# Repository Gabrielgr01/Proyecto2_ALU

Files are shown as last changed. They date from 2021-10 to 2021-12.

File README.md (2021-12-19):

# Diseño e implementación de una ALU
Diseño e implementación de una Unidad Aritmético Lógica (ALU).

Entradas:
- Primer número de 6 bits en complemento a 2
- Segundo número de 6 bits en complemento a 2
- Selector de 3 bits, para seleccionar la operación

Operaciones:
- XOR
- AND
- OR
- Desplazamiento hacia la derecha
- Suma con signo
- Multiplicación con signo
- Resta con signo
- Quintuplicador con signo

Salidas:
- Resultado númerico en complemento a 2
- Bandera de cero
- Bandera de paridad par
- Bandera de desbordamiento (Overflow)

Colaboradores:
- Adrián Dittel Retana
- Gabriel O. González Rodríguez
- Emmanuel Naranjo Blanco
- José Fabio Navarro Naranjo
- David Rodríguez Camacho

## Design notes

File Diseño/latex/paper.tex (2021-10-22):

\documentclass[journal,trans]{IEEEtran}

\usepackage[utf8]{inputenc}
\usepackage{graphicx}
\usepackage[spanish, es-tabla, activeacute]{babel}
\usepackage{verbatim}

\begin{document}

% Do not put math or special symbols in the title.
\newcommand{\titlepaper}{Diseño e Implementación de una ALU}

\title{\titlepaper}

\renewcommand\IEEEkeywordsname{Palabras clave}

\author{\IEEEauthorblockN{Adrián Dittel-Retana, Gabriel O. González-Rodríguez, Emmanuel Naranjo-Blanco, Jose Fabio Navarro-Naranjo, David Rodríguez-Camacho}

\IEEEauthorblockA{adriandittel19@estudiantec.cr}
\IEEEauthorblockA{gabrielgr01@estudiantec.cr}
\IEEEauthorblockA{naranjo760emm@estudiantec.cr}
\IEEEauthorblockA{josefabio1127@estudiantec.cr}
\IEEEauthorblockA{davo4006@estudiantec.cr}
\IEEEauthorblockA{\\Área Académica de Ingeniería Mecatrónica}
\IEEEauthorblockA{\\Instituto Tecnológico de Costa Rica}
}

% The paper headers
\markboth{Dittel, González, Naranjo, Navarro, Rodríguez, \titlepaper}%
{Shell \MakeLowercase{\textit{et al.}}: Bare Demo of IEEEtran.cls for Journals}

\IEEEtitleabstractindextext{%
\begin{abstract}
La Unidad Aritmética Lógica (ALU) consiste en una parte esencial de la unidad central de procesamiento, encargada de realizar operaciones lógicas y aritméticas para cumplir instrucciones dentro de un sistema computacional. En el presente proyecto de laboratorio se presentará una propuesta para el diseño de una ALU que lleva a cabo siete operaciones (lógicas y matemáticas), además de los resultados obtenidos tras su ejecución. La solución a la propuesta se basó fundamentalmente en el uso de lógica combinacional, y a nivel de diseño se utilizó el método de diseño modular, en donde se divide el sistema en subsistemas más pequeños, llamados módulos, a los cuales se les encuentra una solución individual, y reutilizable.  Posteriormente se integran las soluciones para cada módulo y se le agregan las distintas banderas como parte de las restricciones del proyecto. Una vez finalizado el experimento, se llega a la conclusión principal del proyecto: Se verificó mediante el lenguaje de descripción de hardware (HDL), y su implementación en la placa de desarrollo BASYS 3, el correcto funcionamiento de la ALU propuesta mediante la estructura de diseño planteada. Además, de la simulación se obtuvo, para la FPGA utilizada, un bajo consumo de potencia (5.576W) y una utilización del LUT (Look Up Table) de 0.33\%, lo que significa que también hubo un bajo consumo de memoria.
\end{abstract}

\begin{IEEEkeywords}
Diseño modular, ALU, Lógica Combinacional, Verilog.
\end{IEEEkeywords}}

\maketitle
\IEEEdisplaynontitleabstractindextext
\IEEEpeerreviewmaketitle

\section{INTRODUCCIÓN}

Parte fundamental de la electrónica digital consiste en la implementación de los conocimientos en la integración de sistemas completamente funcionales y aplicables para solucionar problemas de la vida real. En el presente proyecto de laboratorio se pretende aplicar la teoría, específicamente aquella relacionada con lógica combinacional, para así emplearla de forma práctica en una Unidad Aritmética Lógica (ALU, por sus siglas en inglés). 

De acuerdo con Tocci, una ALU consiste en un circuito que permite realizar operaciones lógicas y aritméticas \cite{Tocci}. Las cuales se encuentran como parte fundamental de los sistemas tecnológicos actuales como computadoras, celulares y tablets. A su vez, existen presentaciones en circuitos integrados como los chips 74LS382 o 74HC382 cuyo bloque se representa en la Figura \ref{fig:ALU}. 

En este tipo de chips se basa el objetivo específico del proyecto, el cual consiste en implementar un sistema lógico en un ambiente de verificación de hardware. Donde como parte de los objetivos generales se tiene comprender el proceso de diseño y verificación de los sistemas digitales, y aplicar el diseño en una placa de desarrollo. Para este caso se utiliza una matriz de puertas lógicas programable en campo, comúnmente llamada FPGA (Field-Programmable Gate Array).

\begin{figure}[!h]
	\centering
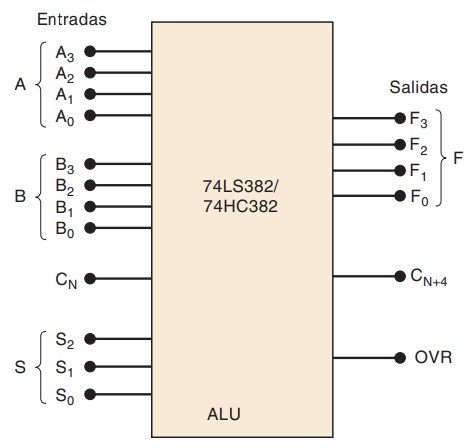
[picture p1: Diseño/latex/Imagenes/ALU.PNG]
	
	\caption{Símbolo de bloque para el chip ALU 74LS382/HC382 \cite{Tocci}.}
	\label{fig:ALU}
\end{figure}

La idea fundamental de este proyecto consiste en diseñar una ALU que realice todas las operaciones descritas en la Tabla \ref{tab:operaciones}. Para esto se tienen dos entradas de datos A y B, y una salida Y, todas con un tamaño constante de palabra de 6 bits y operando bajo el sistema de complemento a dos. Además, las operaciones se escogen mediante un selector SEL de 3 bits y se requiere de tres banderas: cero, paridad par y desbordamiento. 

\begin{table}[!h]
  \begin{center}
    \caption{Descripción de las operaciones de la ALU por diseñar.}
    \label{tab:operaciones}
    \begin{tabular}{c | c | c }
      \hline
      SEL [2:0] & Tipo de Operación & Y \\
      \hline
       000 & XOR & Y = A $\string^$ B \\
       \hline
       001 & AND & Y = A $\&$ B \\
       \hline
       010 & OR & Y = A $\mid$ B \\
       \hline
       011 & Desplazamiento lógico a la derecha & Y=A $\gg$ 1 \\
       \hline
       100 & Suma con signo & Y = A + B \\
       \hline
       101 & Multiplicación con signo & Y = A * B \\
       \hline
       110 & Resta con signo & Y = A - B \\
       \hline
       111 & Quintuplicado de un número & Y = 5 * A \\
      \hline
    \end{tabular}
  \end{center}
\end{table}

Para simular e implementar el diseño propuesto se utiliza la placa BASYS 3 Artix-7 (xc7a35tcpg236-2L), la cual se programa en Verilog, un lenguaje de descripción de hardware (HDL, por sus siglas en inglés) al cual se le realiza una previa simulación para comprobar su correcto funcionamiento.

A modo conceptual, un HDL se trata de un lenguaje de programación para modelar un bloque de hardware, el cual permite simular la operación del circuito antes de fabricarlo \cite{Paulino}. En este caso, se trabajó con el HDL Verilog debido a su popularidad y simplicidad, y por ser estándar en la industria de las FPGA. Para esto, cada componente se describe con módulos y la verificación de este se establece bajo la estructura de un TestBench.

En las siguientes secciones se detallará el proceso de diseño junto con los diagramas modulares realizados y su descripción. Posteriormente se analizarán los resultados obtenidos tanto a nivel físico como simulado mediante el software Vivado. 

\section{DISEÑO DE LA ALU}

Para el desarrollo de la ALU anteriormente descrita, se utilizó un diseño modular, desarrollado y ejemplificado a través de diagramas de primer, segundo y tercer nivel (ver anexos).

Las restricciones previamente definidas para el proyecto son las siguiente:
\begin{itemize}
    \item Implementar todas las operaciones presentes en la tabla \ref{tab:operaciones}.
    \item Para las entradas de datos, debe permitir dos operandos (A y B) con un tamaño de palabra de 6 bits cada una y un selector (SEL) de 3 bits.
    \item Para la salida de datos, el resultado (Y) debe de tener también un tamaño de palabra de 6 bits.
    \item La ALU debe operar bajo el sistema complemento a 2.
    \item Deben implementarse 3 banderas de salida: cero (ZF), paridad par (PZ) y desbordamiento (OF).
\end{itemize}

Tomando en cuenta lo anterior, a continuación se presenta el diseño realizado clasificado en las tres etapas del diseño modular (primero, segundo y tercer nivel).

\subsection{PRIMER NIVEL}
En la figura \ref{fig:diagrama_1nivel} se muestra el diagrama de primer nivel formado a partir de las restricciones del proyecto. En dicha imagen se observan las 3 entradas presentes para el sistema (A y B números de 6 bits cada uno, y SEL de 3 bits), y las 4 salidas esperadas (Y de 6 bits, que es el resultado de la operación, y las 3 banderas de un bit cada una).

\begin{figure}[!h]
	\centering
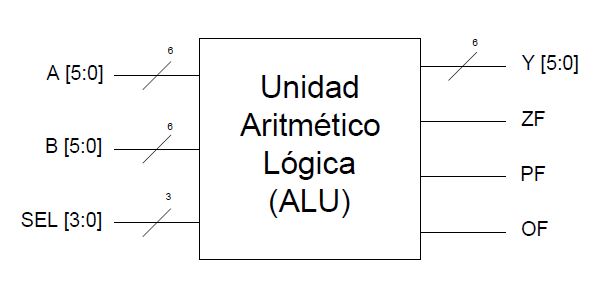
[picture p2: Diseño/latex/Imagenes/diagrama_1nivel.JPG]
	
	\caption{ALU: Diagrama de primer nivel.}
	\label{fig:diagrama_1nivel}
\end{figure}

\subsection{SEGUNDO NIVEL}
En esta sección se decidió asignarle un módulo a cada operación descrita en la tabla \ref{tab:operaciones}, con excepción de las operaciones de suma y resta, que se unieron en un mismo módulo, esto debio a la gran similitud en los circuitos necesarios para realizar estas operaciones. Luego, se juntan por medio de un grupo de multiplexores 8 a 1 (un multiplexor por cada bit), encargado de controlar cuál resultado de las operaciones se transmite a la salida del sistema como Y.

Cada uno de estos módulos tiene como entradas a A y a B (a excepción de la operación de desplazamiento y de quintuplicación, las cuales solo operan con el número definido como A), y como salida al resultado de la operación correspondiente (de 6 bits también). Además, las operaciones de Sumador y restador, Multiplicador y Quintuplicador, poseen una salida extra correspondiente a la bandera de OF, las cuales se toman como entradas en el módulo encargado de ejecutar la bandera OF del sistema. Es importante mencionar, que las operaciones lógicas no tienen una bandera OF, ya que este valor siempre es cero para ellas.

Para finalizar, se agregaron los dos módulos faltantes (para las banderas ZF y PF), los cuales tienen a Y como entrada.

En la Figura \ref{fig:Diagrama_segundo_nivel} de los anexos, se puede observar el diagrama correspondiente a esta sección.

\subsection{TERCER NIVEL}
A continuación se describe el diseño realizado para cada uno de los módulos propuestos en la sección anterior.

\subsubsection{Bandera ZF}
Para la bandera de cero, o la “Zero Flag”, se colocó una compuerta del tipo NOR que toma todos los bits de salida del resultado de las operaciones, de modo que (al ser una compuerta NOR) arroje un 1 únicamente cuando todos los bits de Y sean 0. Este diagrama se puede observar en la Figura \ref{fig:Diagrama_tercer_nivel_ZF} de los anexos.

\subsubsection{Bandera PF}
Para la bandera de paridad par se utilizó una compuerta XNOR, la cual recibe como entrada todos los bits del resultado Y. Debido a su funcionamiento, provocará que la bandera se active (1 lógico) cuando la cantidad de bits iguales a 1 en la entrada sea par. Este diagrama se puede observar en la Figura \ref{fig:Diagrama_tercer_nivel_PF} de los anexos.

\subsubsection{Bandera OF}
Como se mencionó en la sección anterior, se toman todas las banderas de OF a la salida de las operaciones matemáticas y se utilizan como entrada para este módulo, que corresponde a un multiplexor 8 a 1, el cual usa el mismo selector del multiplexor que saca el bus de datos de las operaciones (es decir, el selector de las operaciones lógicas). De esta manera, se conecta la bandera OF del sistema a la salida de este multiplexor, y se refleja el desbordamiento de la operación que se está realizando. Es importante mencionar que las primeras 4 entradas del multiplexor son 0, ya que corresponden al desbordamiento de las operaciones lógicas. Este diagrama se puede observar en la Figura \ref{fig:Diagrama_tercer_nivel_OF} de los anexos. 

Por último, como se diseñó un único módulo para las operaciones de suma y resta, y como la bandera OF del módulo refleja el desbordamiento de la operación que se está realizando, las entradas 4 y 6 del multiplexor se encuentran en corto circuito con la bandera OF a la salida del circuito Sumador/Restador.

\subsubsection{XOR}
Para esta operación se implementó el uso de 6 compuertas XOR, las cuales comparan los bits de A contra los de B en el orden de significancia, es decir, la primera compuerta XOR compara el bit A0 con el bit B0, la segunda compuerta compara el bit A1 con el bit B1, y así sucesivamente. Este diagrama se puede observar en la Figura \ref{fig:Diagrama_tercer_nivel_xor} de los anexos. 

\subsubsection{AND}
El diseño para el circuito que ejecuta esta operación es bastante similar al implementado en la operación anterior, solo que con otro tipo de compuertas lógica. Utiliza 6 compuertas del tipo AND, las cuales comparan bit por bit, las entradas A y B, desde el bit menos significativo, hasta el bit más significativo, de modo que este circuito arroja como salida un bus de 6 bits, que incluye todas las salidas individuales de cada compuerta. Este diagrama se puede observar en la Figura \ref{fig:Diagrama_tercer_nivel_and} de los anexos. 

\subsubsection{OR}
De manera bastante similar a las anteriores, esta operación se realiza con 6 compuertas OR que comparaban uno a uno los bits de las entradas A y B, conforme a su significancia, de modo que al circuito le entran los 6 bits de A, y los 6 bits de B, y tiene como salida un bus de datos que se dirige al multiplexor, y que representa las salidas de cada compuerta OR individual. Este diagrama se puede observar en la Figura \ref{fig:Diagrama_tercer_nivel_or} de los anexos. 

\subsubsection{Desplazamiento lógico a la derecha}
Para el diseño de este circuito lógico, no se utilizó ninguna compuerta lógica. Lo que se realizó fue que se alambraron los bits de A, de modo que calzaran con el bit de Y esperado. Para esto, se utilizó de manera ilustrativa la Tabla 2, con el fin de tener una idea más clara de las conexiones a realizar. Este diagrama se puede observar en la Figura \ref{fig:Diagrama_tercer_nivel_desplazamiento} de los anexos.

\subsubsection{Sumador con signo y Restador con signo}
Para el diseño de estas operaciones se decidió implementarlas en un único circuito, el cual iba a seleccionar que operación realizar según el bit 1 del selector de la ALU (0 para suma y 1 para resta), se utilizó un sumador donde A se conecta directamente a una de sus entradas y B procede de la salida de un multiplexor (Mux) gobernado por SEL[1], en una entrada del Mux B se mantiene igual y en la otra se invierte con compuertas NOT. Igualmente, el acarreo de entrada corresponde a SEL[1]. De este modo, al escoger la suma, A y B se mantienen iguales y Cin = 0, pero al escoger la resta, A se mantiene y se aplica el complemento a 2 de B gracias a que este se niega a causa de la salida del Mux y se suma un 1 con el Cin = 1.

Para determinar si se tenía desbordamiento, se tomó en cuenta que, en la suma esta condición puede ocurrir solo cuando los operandos son del mismo signo y siempre produce un resultado incorrecto. Por otro lado, en la resta el desbordamiento sucede cuando los números tienen signos diferentes, con esto, entonces, al trabajar bajo el sistema de complemento a 2, se sabe que tanto para resta como para suma, si el número es negativo, se realizará el complemento a 2 de este y se hará la operación de suma. Por esta razón, el desbordamiento ocurre únicamente cuando el bit más significativo de los operandos es igual y el bit más significativo del resultado es distinto al MSB de los operandos. Este diagrama se puede observar en la Figura \ref{fig:Diagrama_tercer_nivel_suma_resta} de los anexos.

\subsubsection{Multiplicador con signo}
Para el diseño del multiplicador se utilizó el mismo algoritmo que se utilizaría para resolver una multiplicación binaria en complemento a dos a mano. Primero, se hace la conversión de complemento a 2 a binario natural para los operandos que tengan signo negativo. Segundo, se realiza la multiplicación binaria habitual con ambos operandos en binario natural. Y tercero, se hace una comprobación, por “ley de signos”, para determinar si el resultado debe de tener signo negativo o positivo.

Se hizo un módulo para el conversor de complemento a 2 / binario natural, en el cual se invierte cada bit del dato y luego se le suma uno. Este algoritmo funciona para hacer la conversión en cualquiera de las dos direcciones. Luego, mediante un multiplexor 2 a 1 se elije si transmitir el dato original o su conversión al módulo de multiplicación. La elección se realiza a partir del bit más significativo del dato, que se toma como selector. Al corresponder este al signo, si es positivo (0 lógico) se transmite el dato original y si es negativo (1 lógico) se transmite al conversión.

Se realiza lo anterior para ambos operandos y se procede a realizar la multiplicación en binario natural. Este módulo se construyó a partir de sumadores. El diagrama de este submódulo se puede observar en la figura \ref{fig:Diagrama_tercer_nivel_multiplicadorBinNat} de los anexos.

Por último, con otro multiplexor 2 a 1, se decide si transmitir como resultado del multiplicador el resultado de la multiplicación o su complemento a 2. Para realizar esta elección se toman el bit más significativo de cada operando como entrada de una compuerta XOR, y la salida se conecta al selector. De esta forma si el signo de los operandos es diferente, se transmite el complemento a 2 (resultado negativo), y si es igual, se transmite el resultado sin convertir (resultado positivo). 

El diagrama del multiplicador con signo se puede observar en la Figura \ref{fig:Diagrama_tercer_nivel_multiplicacion} de los anexos.

\subsubsection{Quintuplicador con signo}

En cuanto a la operación del quintuplicador, se hizo la multiplicación por 5 a partir del principio de desplazamiento a la izquierda. Dado que esto solo sirve para multiplicar por números resultantes de \((2^n)\), se separó el cinco en una suma de potencias de 2, \((2^2+2^0)\), entonces se corre el número entrante dos veces a la izquierda y se suma a la entrada original para obtener la función \(x(2^2+2^0)\).

Para esto se utilizó un circuito de dezplazamiento lógico a la izquierda que corre solo un bit entonces se conectan los 6 bits de entrada a este circuito y el resultado de este se vuelve a pasar por el circuito para obtener la multiplicación \((x*2^2)\) y esto es equivalente a multiplicar por 4 y a desplazar el número dos veces, por último este resultado y el número de entrada (sin cambios) del quintuplicador se suman para obtener el valor final de la multiplicación por cinco. 

Se creó un circuito para el desplazador (ver Figura \ref{fig:detalle_quintuplicador} de los anexos: detalle quintuplicador). El cuál es una colección de compuertas AND, OR y un bit de control. Cuando el bit de control es 0 el desplazador va a añadir un cero en la posición del bit menos significativo y las posiciones actuales de los otros bits restantes se cambian por los valores del bit anterior.

\section{IMPLEMENTACIÓN Y ANÁLISIS DE RESULTADOS}

Para realizar la implementación del diseño planteado anteriormente, se conectó la FPGA, para cargar el código generado en Verilog, esto a través de la máquina virtual, con esto entonces, se tomó la decisión de hacer la introducción de datos con los switches, tomando los iniciales del lado derecho y moviendose hacia la izquierda, siendo los primeros 3 switches, los 3 bits del seleccionador, luego los siguientes 6 switches para los bits de la entrada A y luego de la misma forma 6 switches para los 6 bits de B, esto respetando que siempre se inicia con el LSB con el switch más a la derecha; para determinar que valor se obtuvo en la salida Y, se decidió configurar los LEDs iniciando nuevamente a la derecha con el LSB moviendose hacia la izquierda, representando el valor de cada bit de Y, encendido si es 1, y apagado si es 0.

Una vez hecho esto, se hizo un análisis post-implementación para determinar que porcentajes de energía y de área fueron utilizados en el diseño, esto se puede observar en la figura \ref{fig:Resultados}.

\begin{figure}[!h]
	\centering
	
	\caption{Resultados post-implementación de energía y área.}
	\label{fig:Resultados}
\end{figure}

Al observar  los datos obtenidos presentados anteriormente, se tiene que se obtuvo un sistema bastante eficiente en términos de espacio, como se presenta en la tabla \ref{tab:porcentajes}, y también de energía.

\begin{table}[!h]
  \begin{center}
    \caption{Porcentajes de utilización.}
    \label{tab:porcentajes}
    \begin{tabular}{c | c | c | c }
      \hline
      Recurso & Utilización & Disponible & Utilización (Porcentual\\
      \hline
       LUT & 68 & 20800 & 0.33 \\
    \end{tabular}
  \end{center}
\end{table}

En el aspecto de área de memoria utlizada, se tiene que, con un 0.33\% de la memoria total, el recurso utilizado es poco en comparación a todo el disponible, como se observa en la tabla \ref{tab:porcentajes}. Siendo este valor ni siquiera el 1\%, se puede concluir que el diseño planteado es de alta eficiencia, ya que al utilizar tan poco espacio permite que la FPGA, pueda llevar a cabo todas las operaciones planteadas de forma cómoda y sin problemas.

Por el otro lado, al analizar cuánta energía fue utilizada por la placa, se tiene que esta consumió una potencia de 5.576W, siendo 4.424W de los inputs y outputs del sistema y 0.486W de la lógica combinacional implementada en el diseño, como se ve en la figura \ref{fig:Resultados}. Por lo que, de toda la potencia utlizada, sólo el 9\% es dedicada a la lógica. Con todo lo anterior, se determina que el diseño planteado así como su construcción son sumamente eficientes en ambos aspectos evaluados.

\section{CONCLUSIONES}
A partir de este presente trabajo, se logró concluir lo siguiente.
\begin{itemize}
    \item El diseño propuesto realiza todas las operaciones lógicas y aritmeticas implementadas de forma correcta.
    \item El diseño propuesto obtuvo un bajo consumo de potencia (5.576W) para la FPGA BASYS 3 Artix-7.
    \item El diseño propuesto obtuvo un bajo consumo de memoria, 0.33\% del LUT, para la FPGA BASYS 3 Artix-7.
    \item Se obutvo el comportamiento esperado al realizar la implementación en la FPGA BASYS 3 Artix-7. Comprobando así la correctitud de las operaciones lógicas y aritméticas implementadas.
\end{itemize}

\section{RECOMENDACIONES}
Para realizar exitosamente el proyecto es necesario cumplir una serie de recomendaciones.
\begin{itemize}
    \item Es indispensable la partición del problema en subsistemas (diseño modular) por dos razones, para familiarizarse con los estándares de diseño y para comprender el proceso de solucionar sistemas digitales complejos que por medio de otras herramientas como tablas de verdad o funciones lógicas únicamente, no se podría, o se volvería innecesariamente complicado.
    \item La utilización de diseño modular facilita considerablemente la depuración en caso de cometer un error.
    \item Es de suma importancia que a la hora de crear los diseños se hagan con la simplificación al máximo ya que esto permite lograr bajos valores de consumo de energía y espacio.
    \item Para cada nuevo módulo que se cree en Verilog se debe de hacer su correspondiente TestBench para garantizar que el funcionamiento es el que se planteó, de igual forma, probarlo con la mayor cantidad de casos posibles.
\end{itemize}

\section{ANEXOS}
En esta sección se presentan los diversos diagramas de segundo y tercer nivel que representan todos los aspectos del diseño propuesto. Se incluyen el diagrama general de la solución y los diagramas para todas las operaciones (tanto lógicas como matemáticas) así como para las banderas solicitadas.

\begin{figure}[h!]
	\centering
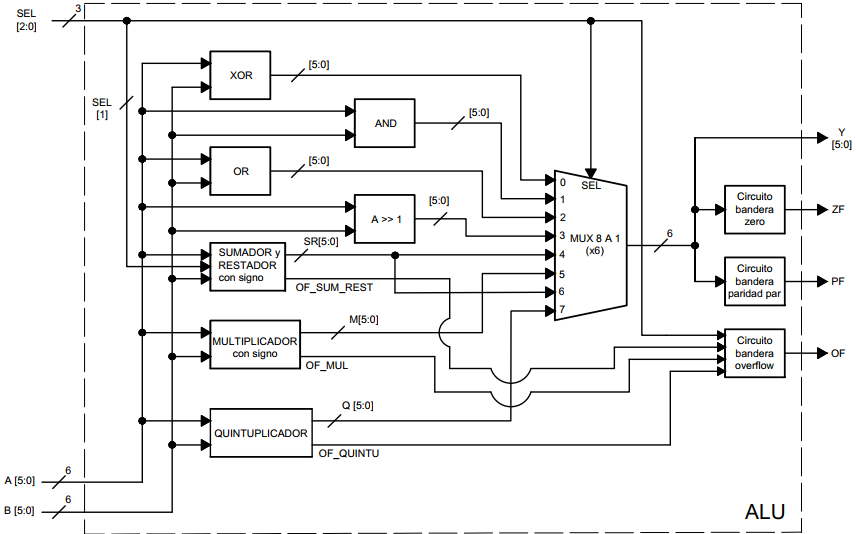
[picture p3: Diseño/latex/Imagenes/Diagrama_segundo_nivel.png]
	
	\caption{ALU: Diagrama de segundo nivel.}
	\label{fig:Diagrama_segundo_nivel}
\end{figure}

\begin{figure}[h!]
	\centering
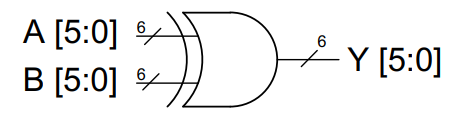
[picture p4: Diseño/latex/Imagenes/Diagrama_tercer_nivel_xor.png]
	
	\caption{ALU: Diagrama de tercer nivel de la operación XOR.}
	\label{fig:Diagrama_tercer_nivel_xor}
\end{figure}

\begin{figure}[h!]
	\centering
	
	\caption{ALU: Diagrama de tercer nivel de la operación AND.}
	\label{fig:Diagrama_tercer_nivel_and}
\end{figure}

\begin{figure}[h!]
	\centering
	
	\caption{ALU: Diagrama de tercer nivel de la operación OR.}
	\label{fig:Diagrama_tercer_nivel_or}
\end{figure}

\begin{figure}[h!]
	\centering
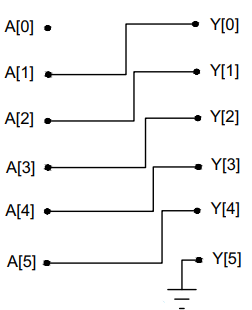
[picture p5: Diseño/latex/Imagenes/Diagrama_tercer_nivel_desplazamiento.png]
	
	\caption{ALU: Diagrama de tercer nivel de la operación desplazamiento lógico a la derecha.}
	\label{fig:Diagrama_tercer_nivel_desplazamiento}
\end{figure}

\begin{figure}[h!]
	\centering
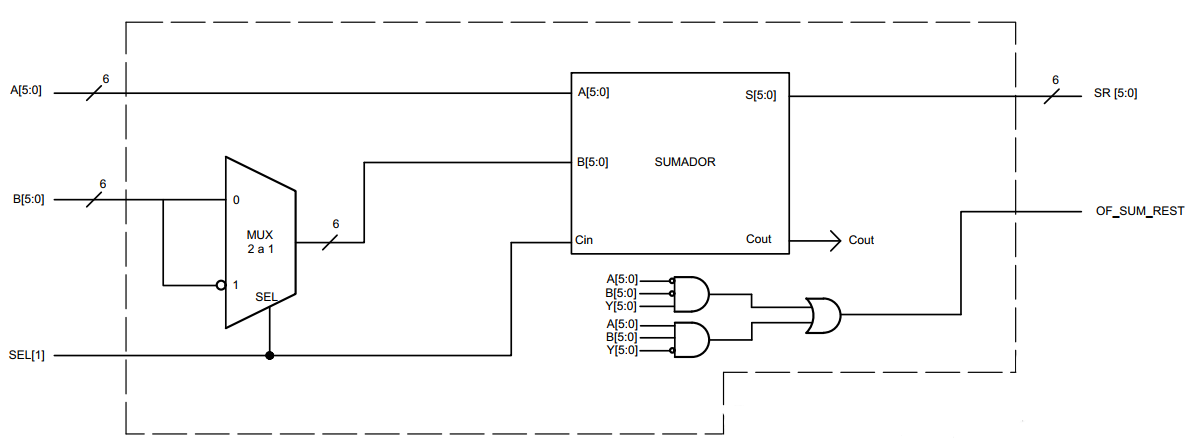
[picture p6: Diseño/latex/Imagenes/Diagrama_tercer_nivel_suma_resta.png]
	
	\caption{ALU: Diagrama de tercer nivel de las operaciones de suma y resta con signo.}
	\label{fig:Diagrama_tercer_nivel_suma_resta}
\end{figure}

\begin{figure}[h!]
	\centering
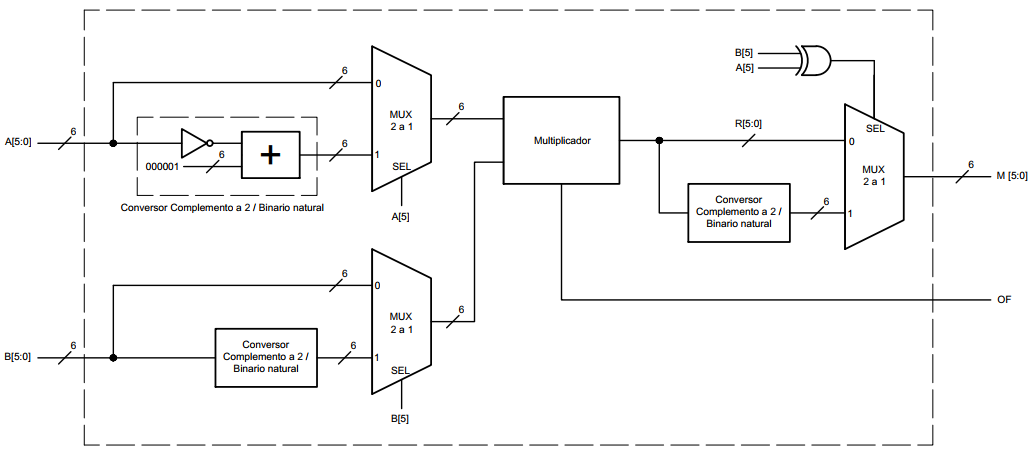
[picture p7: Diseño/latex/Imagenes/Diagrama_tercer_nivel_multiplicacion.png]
	
	\caption{ALU: Diagrama de tercer nivel de la operación de multiplicación con signo.}
	\label{fig:Diagrama_tercer_nivel_multiplicacion}
\end{figure}

\begin{figure}[h!]
	\centering
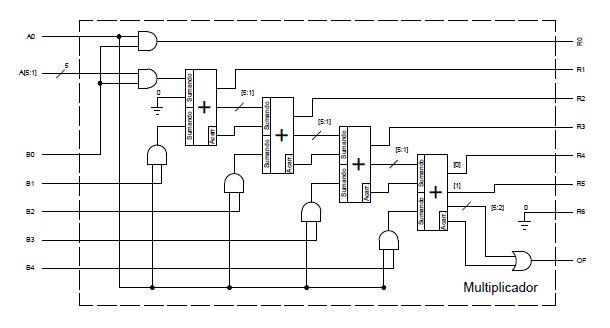
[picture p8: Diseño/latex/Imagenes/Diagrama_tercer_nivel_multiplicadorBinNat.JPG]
	
	\caption{ALU: Diagrama de tercer nivel del submódulo correspondiente al multiplicador en binario natural.}
	\label{fig:Diagrama_tercer_nivel_multiplicadorBinNat}
\end{figure}

\begin{figure}[h!]
	\centering
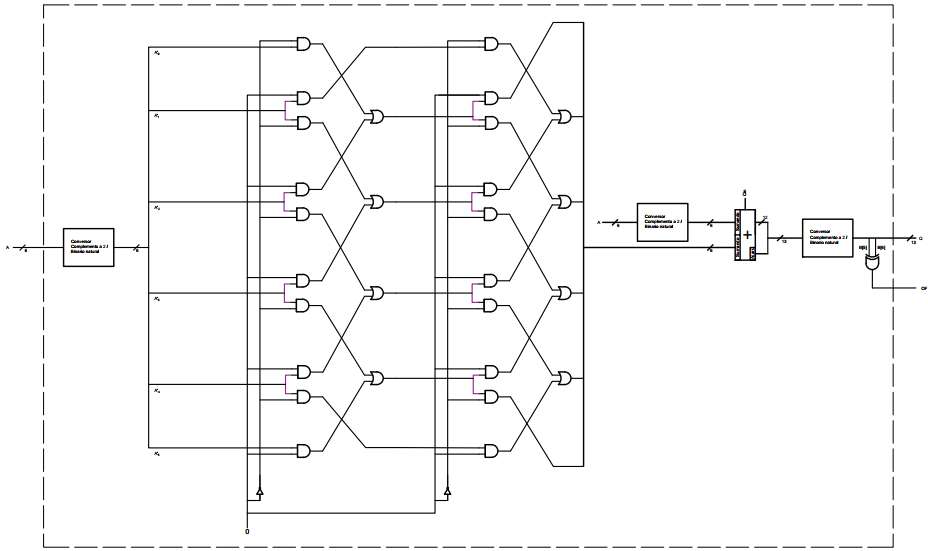
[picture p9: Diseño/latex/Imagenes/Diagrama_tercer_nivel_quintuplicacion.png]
	
	\caption{ALU: Diagrama de tercer nivel de la operación de quintuplicado de un número.}
	\label{fig:Diagrama_tercer_nivel_quintuplicacion}
\end{figure}

\begin{figure}[h!]
	\centering
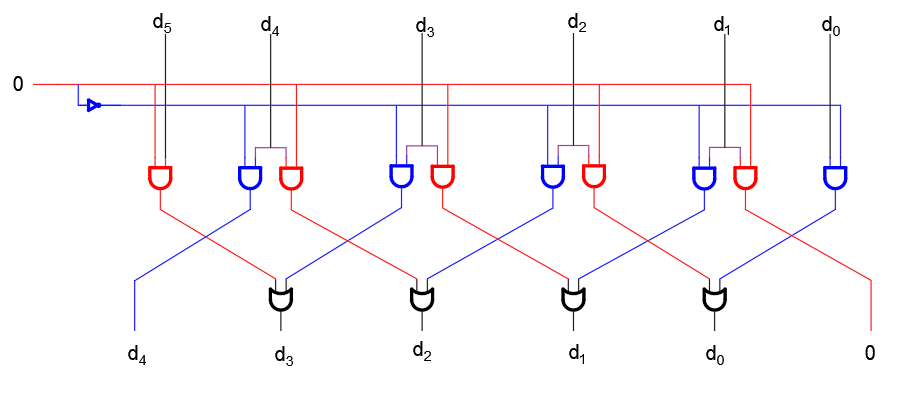
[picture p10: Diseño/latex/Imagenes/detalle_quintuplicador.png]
	
	\caption{ALU: Detalle del circuito quintuplicador de un número.}
	\label{fig:detalle_quintuplicador}
\end{figure}

\begin{figure}[h!]
	\centering
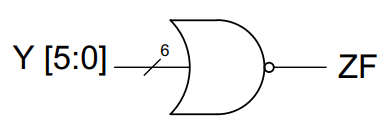
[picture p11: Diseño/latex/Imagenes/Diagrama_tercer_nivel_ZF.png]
	
	\caption{ALU: Diagrama de tercer nivel para la bandera ZF.}
	\label{fig:Diagrama_tercer_nivel_ZF}
\end{figure}

\begin{figure}[h!]
	\centering
	
	\caption{ALU: Diagrama de tercer nivel para la bandera PF.}
	\label{fig:Diagrama_tercer_nivel_PF}
\end{figure}

\begin{figure}[h!]
	\centering
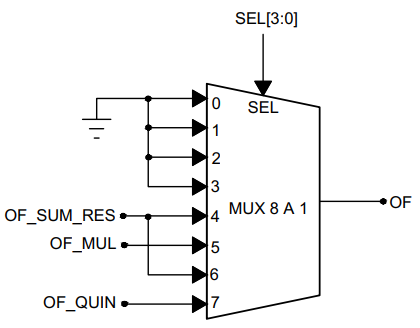
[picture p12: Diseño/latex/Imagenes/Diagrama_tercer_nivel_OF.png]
	
	\caption{ALU: Diagrama de tercer nivel para la bandera OF.}
	\label{fig:Diagrama_tercer_nivel_OF}
\end{figure}

\newpage

\begin{thebibliography}{1}

\bibitem{Tocci}
R. Tocci. \emph{Sistemas digitales: Principios y aplicaciones}. Décima edición. Pearson Education. 2007.

\bibitem{Paulino}
Paulino Ruiz de Clavijo Vásquez. \emph{Introducción a HDL Verilog - Presentaciones de clase}. Departamento de Tecnología Electrónica. Universidad de Sevilla.

\end{thebibliography}

\end{document}

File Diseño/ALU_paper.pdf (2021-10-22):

DITTEL, GONZALEZ, NARANJO, NAVARRO, RODR ´ | ÍGUEZ, DISENO E IMPLEMENTACI ˜ | ON DE UNA ALU | 1 ´
Diseno e Implementaci ˜ | on de una ALU ´
Adrian Dittel-Retana, Gabriel O. Gonz ´ | alez-Rodr ´ | íguez, Emmanuel Naranjo-Blanco, Jose Fabio Navarro-Naranjo,
David Rodríguez-Camacho
adriandittel19@estudiantec.cr gabrielgr01@estudiantec.cr naranjo760emm@estudiantec.cr josefabio1127@estudiantec.cr davo4006@estudiantec.cr
Area Acad ´ | emica de Ingenier ´ | ía Mecatronica ´
Instituto Tecnologico de Costa Rica ´
Resumen—La Unidad Aritmetica L ´ | ogica (ALU) consiste en ´
una parte esencial de la unidad central de procesamiento,
encargada de realizar operaciones logicas y aritm ´ | eticas para ´
cumplir instrucciones dentro de un sistema computacional. En el presente proyecto de laboratorio se presentara una propuesta ´ para el diseno de una ALU que lleva a cabo siete operaciones ˜
(logicas y matem ´ | aticas), adem ´ | as de los resultados obtenidos tras ´
su ejecucion. La soluci ´ | on a la propuesta se bas ´ | o fundamental- ´
mente en el uso de logica combinacional, y a nivel de dise ´ | nõ
se utilizo el m ´ | etodo de dise ´ | no modular, en donde se divide el ˜
sistema en subsistemas mas peque ´ | nos, llamados m ˜ | odulos, a los ´
cuales se les encuentra una solucion individual, y reutilizable. ´ Posteriormente se integran las soluciones para cada modulo y se ´ le agregan las distintas banderas como parte de las restricciones del proyecto. Una vez finalizado el experimento, se llega a la
conclusion principal del proyecto: Se verific ´ | o mediante el lenguaje ´
de descripcion de hardware (HDL), y su implementaci ´ | on en la ´
placa de desarrollo BASYS 3, el correcto funcionamiento de la ALU propuesta mediante la estructura de diseno planteada. ˜
Ademas, de la simulaci ´ | on se obtuvo, para la FPGA utilizada, un ´
bajo consumo de potencia (5.576W) y una utilizacion del LUT ´ (Look Up Table) de 0.33 %, lo que significa que tambien hubo ´ un bajo consumo de memoria.
Palabras clave—Diseno modular, ALU, L ˜ | ogica Combinacional, ´
Verilog.
I. INTRODUCCION´

Parte fundamental de la electronica digital consiste en la ´
implementacion de los conocimientos en la integraci ´ | on de sis- ´
temas completamente funcionales y aplicables para solucionar problemas de la vida real. En el presente proyecto de laboratorio se pretende aplicar la teoría, específicamente aquella
relacionada con logica combinacional, para as ´ | í emplearla de
forma practica en una Unidad Aritm ´ | etica L ´ | ogica (ALU, por ´
sus siglas en ingles). ´
De acuerdo con Tocci, una ALU consiste en un circuito
que permite realizar operaciones logicas y aritm ´ | eticas [1]. Las ´
cuales se encuentran como parte fundamental de los sistemas tecnologicos actuales como computadoras, celulares y tablets. ´ A su vez, existen presentaciones en circuitos integrados como los chips 74LS382 o 74HC382 cuyo bloque se representa en la Figura 1.
En este tipo de chips se basa el objetivo específico del proyecto, el cual consiste en implementar un sistema logico en ´ un ambiente de verificacion de hardware. Donde como parte ´ de los objetivos generales se tiene comprender el proceso de
diseno y verificaci ˜ | on de los sistemas digitales, y aplicar el ´
diseno en una placa de desarrollo. Para este caso se utiliza una ˜
matriz de puertas logicas programable en campo, com ´ | unmente ´
llamada FPGA (Field-Programmable Gate Array).


Figura 1. Símbolo de bloque para el chip ALU 74LS382/HC382 [1].

La idea fundamental de este proyecto consiste en disenar ˜ una ALU que realice todas las operaciones descritas en la Tabla I. Para esto se tienen dos entradas de datos A y B, y una salida Y, todas con un tamano constante de palabra ˜ de 6 bits y operando bajo el sistema de complemento a dos. Ademas, las operaciones se escogen mediante un selector SEL ´ de 3 bits y se requiere de tres banderas: cero, paridad par y desbordamiento.

Tabla I
DESCRIPCION DE LAS OPERACIONES DE LA ´ | ALU POR DISENAR ˜ | .
SEL [2:0] | Tipo de Operacion´ | Y
000 | XOR | Y = A ˆ B
001 | AND | Y = A & B
010 | OR | Y = A | B
011 | Desplazamiento logico a la derecha ´ | Y=A 1
100 | Suma con signo | Y = A + B
101 | Multiplicacion con signo ´ | Y = A * B
110 | Resta con signo | Y = A - B
111 | Quintuplicado de un numero ´ | Y = 5 * A

Para simular e implementar el diseno propuesto se utiliza ˜ la placa BASYS 3 Artix-7 (xc7a35tcpg236-2L), la cual se programa en Verilog, un lenguaje de descripcion de hardware ´ (HDL, por sus siglas en ingles) al cual se le realiza una previa ´ simulacion para comprobar su correcto funcionamiento. ´

DITTEL, GONZALEZ, NARANJO, NAVARRO, RODR ´ | ÍGUEZ, DISENO E IMPLEMENTACI ˜ | ON DE UNA ALU | 2 ´

A modo conceptual, un HDL se trata de un lenguaje de
programacion para modelar un bloque de hardware, el cual ´
permite simular la operacion del circuito antes de fabricarlo ´ [2]. En este caso, se trabajo con el HDL Verilog debido a su ´ popularidad y simplicidad, y por ser estandar en la industria ´ de las FPGA. Para esto, cada componente se describe con
modulos y la verificaci ´ | on de este se establece bajo la estructura ´
de un TestBench.
En las siguientes secciones se detallara el proceso de dise ´ | nõ
junto con los diagramas modulares realizados y su descripcion. ´ Posteriormente se analizaran los resultados obtenidos tanto a ´ nivel físico como simulado mediante el software Vivado.

II. DISENO DE LA ALU ˜

Para el desarrollo de la ALU anteriormente descrita, se
utilizo un dise ´ | no modular, desarrollado y ejemplificado a ˜
traves de diagramas de primer, segundo y tercer nivel (ver ´ anexos).
Las restricciones previamente definidas para el proyecto son las siguiente:

Implementar todas las operaciones presentes en la tabla I.
Para las entradas de datos, debe permitir dos operandos (A y B) con un tamano de palabra de 6 bits cada una y ˜ un selector (SEL) de 3 bits.
Para la salida de datos, el resultado (Y) debe de tener
tambien un tama ´ | no de palabra de 6 bits. ˜
La ALU debe operar bajo el sistema complemento a 2. Deben implementarse 3 banderas de salida: cero (ZF), paridad par (PZ) y desbordamiento (OF).

Tomando en cuenta lo anterior, a continuacion se presenta ´
el diseno realizado clasificado en las tres etapas del dise ˜ | nõ
modular (primero, segundo y tercer nivel).

II-A. PRIMER NIVEL

En la figura 2 se muestra el diagrama de primer nivel formado a partir de las restricciones del proyecto. En dicha imagen se observan las 3 entradas presentes para el sistema (A y B numeros de 6 bits cada uno, y SEL de 3 bits), y las ´ 4 salidas esperadas (Y de 6 bits, que es el resultado de la operacion, y las 3 banderas de un bit cada una). ´

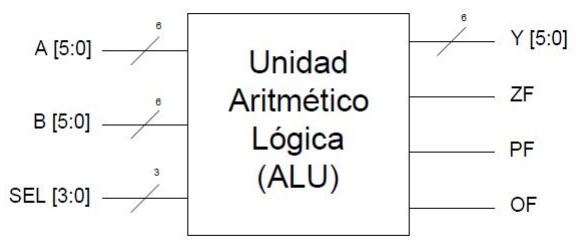
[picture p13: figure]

Figura 2. ALU: Diagrama de primer nivel.

II-B. SEGUNDO NIVEL
En esta seccion se decidi ´ | o asignarle un m ´ | odulo a cada ´
operacion descrita en la tabla I, con excepci ´ | on de las opera- ´
ciones de suma y resta, que se unieron en un mismo modulo, ´ esto debio a la gran similitud en los circuitos necesarios para realizar estas operaciones. Luego, se juntan por medio de un grupo de multiplexores 8 a 1 (un multiplexor por cada bit), encargado de controlar cual resultado de las operaciones se ´ transmite a la salida del sistema como Y.
Cada uno de estos modulos tiene como entradas a A ´
y a B (a excepcion de la operaci ´ | on de desplazamiento y ´
de quintuplicacion, las cuales solo operan con el n ´ | umero ´
definido como A), y como salida al resultado de la operacion´
correspondiente (de 6 bits tambien). Adem ´ | as, las operaciones ´
de Sumador y restador, Multiplicador y Quintuplicador, poseen una salida extra correspondiente a la bandera de OF, las cuales se toman como entradas en el modulo encargado de ejecutar ´ la bandera OF del sistema. Es importante mencionar, que las operaciones logicas no tienen una bandera OF, ya que este ´ valor siempre es cero para ellas.
Para finalizar, se agregaron los dos modulos faltantes (para ´ las banderas ZF y PF), los cuales tienen a Y como entrada. En la Figura 4 de los anexos, se puede observar el diagrama correspondiente a esta seccion. ´

II-C. TERCER NIVEL
A continuacion se describe el dise ´ | | no realizado para cada ˜
uno de los modulos propuestos en la secci ´ | on anterior. ´
II-C1. Bandera ZF: Para la bandera de cero, o la “Zero Flag”, se coloco una compuerta del tipo NOR que toma todos ´ los bits de salida del resultado de las operaciones, de modo que (al ser una compuerta NOR) arroje un 1 unicamente cuando ´ todos los bits de Y sean 0. Este diagrama se puede observar en la Figura 14 de los anexos.
II-C2. Bandera PF: Para la bandera de paridad par se utilizo una compuerta XNOR, la cual recibe como entrada ´ todos los bits del resultado Y. Debido a su funcionamiento,
provocara que la bandera se active (1 l ´ | ogico) cuando la ´
cantidad de bits iguales a 1 en la entrada sea par. Este diagrama se puede observar en la Figura 15 de los anexos.
II-C3. Bandera OF: Como se menciono en la secci ´ | on´
anterior, se toman todas las banderas de OF a la salida de las operaciones matematicas y se utilizan como entrada para este ´ modulo, que corresponde a un multiplexor 8 a 1, el cual usa el ´ mismo selector del multiplexor que saca el bus de datos de las operaciones (es decir, el selector de las operaciones logicas). ´ De esta manera, se conecta la bandera OF del sistema a la salida de este multiplexor, y se refleja el desbordamiento de
la operacion que se est ´ | a realizando. Es importante mencionar ´
que las primeras 4 entradas del multiplexor son 0, ya que corresponden al desbordamiento de las operaciones logicas. ´ Este diagrama se puede observar en la Figura 16 de los anexos.
Por ultimo, como se dise ´ | nõ un ´ | unico m ´ | odulo para las ´
operaciones de suma y resta, y como la bandera OF del
modulo refleja el desbordamiento de la operaci ´ | on que se est ´ | á
realizando, las entradas 4 y 6 del multiplexor se encuentran en corto circuito con la bandera OF a la salida del circuito Sumador/Restador.

DITTEL, GONZALEZ, NARANJO, NAVARRO, RODR ´ | ÍGUEZ, DISENO E IMPLEMENTACI ˜ | ON DE UNA ALU | 3 ´
II-C4. XOR: Para esta operacion se implement ´ | o el uso ´
de 6 compuertas XOR, las cuales comparan los bits de A
contra los de B en el orden de significancia, es decir, la primera compuerta XOR compara el bit A0 con el bit B0, la segunda compuerta compara el bit A1 con el bit B1, y así sucesivamente. Este diagrama se puede observar en la Figura 5 de los anexos.
II-C5. AND: El diseno para el circuito que ejecuta esta ˜
operacion es bastante similar al implementado en la operaci ´ | on´
anterior, solo que con otro tipo de compuertas logica. Utiliza 6 ´ compuertas del tipo AND, las cuales comparan bit por bit, las entradas A y B, desde el bit menos significativo, hasta el bit mas significativo, de modo que este circuito arroja como salida ´ un bus de 6 bits, que incluye todas las salidas individuales de cada compuerta. Este diagrama se puede observar en la Figura 6 de los anexos.
II-C6. OR: De manera bastante similar a las anteriores, esta operacion se realiza con 6 compuertas OR que compara- ´ ban uno a uno los bits de las entradas A y B, conforme a su significancia, de modo que al circuito le entran los 6 bits de A, y los 6 bits de B, y tiene como salida un bus de datos que se dirige al multiplexor, y que representa las salidas de cada compuerta OR individual. Este diagrama se puede observar en la Figura 7 de los anexos.
II-C7. Desplazamiento logico a la derecha: ´ | | Para el disenõ
de este circuito logico, no se utiliz ´ | o ninguna compuerta l ´ | ogica. ´
Lo que se realizo fue que se alambraron los bits de A, de modo ´ que calzaran con el bit de Y esperado. Para esto, se utilizo de ´ manera ilustrativa la Tabla 2, con el fin de tener una idea mas´ clara de las conexiones a realizar. Este diagrama se puede observar en la Figura 8 de los anexos.
II-C8. Sumador con signo y Restador con signo: Para el
diseno de estas operaciones se decidi ˜ | o implementarlas en un ´
unico circuito, el cual iba a seleccionar que operaci ´ | on realizar ´
segun el bit 1 del selector de la ALU (0 para suma y 1 para ´ resta), se utilizo un sumador donde A se conecta directamente ´ a una de sus entradas y B procede de la salida de un multiplexor (Mux) gobernado por SEL[1], en una entrada del Mux B se mantiene igual y en la otra se invierte con compuertas NOT. Igualmente, el acarreo de entrada corresponde a SEL[1]. De este modo, al escoger la suma, A y B se mantienen iguales y Cin = 0, pero al escoger la resta, A se mantiene y se aplica el complemento a 2 de B gracias a que este se niega a causa de la salida del Mux y se suma un 1 con el Cin = 1.
Para determinar si se tenía desbordamiento, se tomo en ´ cuenta que, en la suma esta condicion puede ocurrir solo ´ cuando los operandos son del mismo signo y siempre produce un resultado incorrecto. Por otro lado, en la resta el desbordamiento sucede cuando los numeros tienen signos diferentes, ´ con esto, entonces, al trabajar bajo el sistema de complemento a 2, se sabe que tanto para resta como para suma, si el numero ´
es negativo, se realizara el complemento a 2 de este y se har ´ | á
la operacion de suma. Por esta raz ´ | on, el desbordamiento ocurre ´
unicamente cuando el bit m ´ | as significativo de los operandos ´
es igual y el bit mas significativo del resultado es distinto al ´ MSB de los operandos. Este diagrama se puede observar en la Figura 9 de los anexos.

II-C9. Multiplicador con signo: Para el diseno del multi- ˜
plicador se utilizo el mismo algoritmo que se utilizar ´ | | ía para
resolver una multiplicacion binaria en complemento a dos ´ a mano. Primero, se hace la conversion de complemento ´ a 2 a binario natural para los operandos que tengan signo negativo. Segundo, se realiza la multiplicacion binaria habitual ´ con ambos operandos en binario natural. Y tercero, se hace una comprobacion, por “ley de signos”, para determinar si el ´ resultado debe de tener signo negativo o positivo.
Se hizo un modulo para el conversor de complemento a ´ 2 / binario natural, en el cual se invierte cada bit del dato y luego se le suma uno. Este algoritmo funciona para hacer la conversion en cualquiera de las dos direcciones. Luego, ´ mediante un multiplexor 2 a 1 se elije si transmitir el dato
original o su conversion al m ´ | odulo de multiplicaci ´ | on. La ´
eleccion se realiza a partir del bit m ´ | as significativo del dato, ´
que se toma como selector. Al corresponder este al signo, si es positivo (0 logico) se transmite el dato original y si es negativo ´
(1 logico) se transmite al conversi ´ | on. ´
Se realiza lo anterior para ambos operandos y se procede
a realizar la multiplicacion en binario natural. Este m ´ | | odulo ´
se construyo a partir de sumadores. El diagrama de este ´ submodulo se puede observar en la figura 11 de los anexos. ´ Por ultimo, con otro multiplexor 2 a 1, se decide si transmitir ´ como resultado del multiplicador el resultado de la multipli-
cacion o su complemento a 2. Para realizar esta elecci ´ | | on se ´
toman el bit mas significativo de cada operando como entrada ´ de una compuerta XOR, y la salida se conecta al selector. De esta forma si el signo de los operandos es diferente, se transmite el complemento a 2 (resultado negativo), y si es igual, se transmite el resultado sin convertir (resultado positivo).
El diagrama del multiplicador con signo se puede observar en la Figura 10 de los anexos.

II-C10. Quintuplicador con signo: En cuanto a la ope-
racion del quintuplicador, se hizo la multiplicaci ´ | on por 5 a ´
partir del principio de desplazamiento a la izquierda. Dado que esto solo sirve para multiplicar por numeros resultantes ´ de (2n), se separo el cinco en una suma de potencias de 2, ´ (2² + 2⁰
), entonces se corre el numero entrante dos veces a ´ la izquierda y se suma a la entrada original para obtener la funcion´ x(2² + 2⁰
).
Para esto se utilizo un circuito de dezplazamiento l ´ | | ogico a ´
la izquierda que corre solo un bit entonces se conectan los 6 bits de entrada a este circuito y el resultado de este se vuelve a pasar por el circuito para obtener la multiplicacion´ (x∗2

2
) y esto es equivalente a multiplicar por 4 y a desplazar
el numero dos veces, por ´ | ultimo este resultado y el n ´ | umero ´
de entrada (sin cambios) del quintuplicador se suman para obtener el valor final de la multiplicacion por cinco. ´
Se creo un circuito para el desplazador (ver Figura 13 de ´
los anexos: detalle quintuplicador). El cual es una colecci ´ | on´
de compuertas AND, OR y un bit de control. Cuando el bit de
control es 0 el desplazador va a anadir un cero en la posici ˜ | on´
del bit menos significativo y las posiciones actuales de los otros bits restantes se cambian por los valores del bit anterior.

DITTEL, GONZALEZ, NARANJO, NAVARRO, RODR ´ | ÍGUEZ, DISENO E IMPLEMENTACI ˜ | ON DE UNA ALU | 4 ´
III. IMPLEMENTACION Y AN ´ | ALISIS DE ´
RESULTADOS
Para realizar la implementacion del dise ´ | no planteado ante- ˜
riormente, se conecto la FPGA, para cargar el c ´ | odigo generado ´
en Verilog, esto a traves de la m ´ | aquina virtual, con esto ´
entonces, se tomo la decisi ´ | on de hacer la introducci ´ | on de datos ´
con los switches, tomando los iniciales del lado derecho y moviendose hacia la izquierda, siendo los primeros 3 switches, los 3 bits del seleccionador, luego los siguientes 6 switches para los bits de la entrada A y luego de la misma forma 6 switches para los 6 bits de B, esto respetando que siempre se inicia con el LSB con el switch mas a la derecha; para ´ determinar que valor se obtuvo en la salida Y, se decidió configurar los LEDs iniciando nuevamente a la derecha con el LSB moviendose hacia la izquierda, representando el valor de cada bit de Y, encendido si es 1, y apagado si es 0.
Una vez hecho esto, se hizo un analisis post-implementaci ´ | on´
para determinar que porcentajes de energía y de area fueron ´ utilizados en el diseno, esto se puede observar en la figura 3. ˜

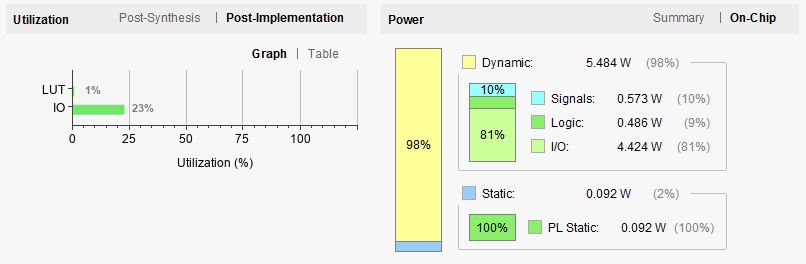
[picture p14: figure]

Figura 3. Resultados post-implementacion de energ ´ | ía y area. ´

Al observar los datos obtenidos presentados anteriormente, se tiene que se obtuvo un sistema bastante eficiente en termi- ´ nos de espacio, como se presenta en la tabla II, y tambien de ´ energía.

Tabla II
PORCENTAJES DE UTILIZACION´ .
Recurso | Utilizacion´ | Disponible | Utilizacion (Porcentual ´
LUT | 68 | 20800 | 0.33

En el aspecto de area de memoria utlizada, se tiene que, con ´ un 0.33 % de la memoria total, el recurso utilizado es poco en comparacion a todo el disponible, como se observa en la tabla ´ II. Siendo este valor ni siquiera el 1 %, se puede concluir que el diseno planteado es de alta eficiencia, ya que al utilizar tan ˜ poco espacio permite que la FPGA, pueda llevar a cabo todas las operaciones planteadas de forma comoda y sin problemas. ´
Por el otro lado, al analizar cuanta energ ´ | ía fue utilizada por
la placa, se tiene que esta consumio una potencia de 5.576W, ´ siendo 4.424W de los inputs y outputs del sistema y 0.486W
de la logica combinacional implementada en el dise ´ | no, como ˜
se ve en la figura 3. Por lo que, de toda la potencia utlizada,
solo el 9 % es dedicada a la l ´ | ogica. Con todo lo anterior, se ´
determina que el diseno planteado as ˜ | í como su construccion´
son sumamente eficientes en ambos aspectos evaluados.

IV. CONCLUSIONES
A partir de este presente trabajo, se logro concluir lo ´ siguiente.
El diseno propuesto realiza todas las operaciones l ˜ | | ogicas ´
y aritmeticas implementadas de forma correcta.
El diseno propuesto obtuvo un bajo consumo de potencia ˜ (5.576W) para la FPGA BASYS 3 Artix-7.
El diseno propuesto obtuvo un bajo consumo de memo- ˜ ria, 0.33 % del LUT, para la FPGA BASYS 3 Artix-7. Se obutvo el comportamiento esperado al realizar la implementacion en la FPGA BASYS 3 Artix-7. Com- ´ probando así la correctitud de las operaciones logicas y ´ aritmeticas implementadas. ´
V. RECOMENDACIONES
Para realizar exitosamente el proyecto es necesario cumplir una serie de recomendaciones.
Es indispensable la particion del problema en subsistemas ´ (diseno modular) por dos razones, para familiarizarse ˜
con los estandares de dise ´ | no y para comprender el ˜
proceso de solucionar sistemas digitales complejos que por medio de otras herramientas como tablas de verdad o
funciones logicas ´ | unicamente, no se podr ´ | ía, o se volvería
innecesariamente complicado.
La utilizacion de dise ´ | no modular facilita considerable- ˜
mente la depuracion en caso de cometer un error. ´
Es de suma importancia que a la hora de crear los disenos ˜
se hagan con la simplificacion al m ´ | aximo ya que esto ´
permite lograr bajos valores de consumo de energía y espacio.
Para cada nuevo modulo que se cree en Verilog se debe ´ de hacer su correspondiente TestBench para garantizar que el funcionamiento es el que se planteo, de igual ´ forma, probarlo con la mayor cantidad de casos posibles.
| VI. ANEXOS
En esta seccion se presentan los diversos diagramas de ´ segundo y tercer nivel que representan todos los aspectos del diseno propuesto. Se incluyen el diagrama general de la solu- ˜
cion y los diagramas para todas las operaciones (tanto l ´ | ogicas ´
como matematicas) as ´ | í como para las banderas solicitadas.

DITTEL, GONZALEZ, NARANJO, NAVARRO, RODR ´ | ÍGUEZ, DISENO E IMPLEMENTACI ˜ | ON DE UNA ALU | 5 ´


Figura 4. ALU: Diagrama de segundo nivel.

Figura 5. ALU: Diagrama de tercer nivel de la operacion XOR. ´

Figura 6. ALU: Diagrama de tercer nivel de la operacion AND. ´

Figura 7. ALU: Diagrama de tercer nivel de la operacion OR. ´

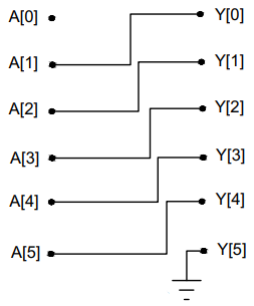
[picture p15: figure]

Figura 8. ALU: Diagrama de tercer nivel de la operacion desplazamiento ´ logico a la derecha. ´

REFERENCIAS

[1] R. Tocci. Sistemas digitales: Principios y aplicaciones. Decima edici ´ | on. ´
Pearson Education. 2007.
[2] Paulino Ruiz de Clavijo Vasquez. ´ | Introduccion a HDL Verilog - Presen- ´
taciones de clase. Departamento de Tecnología Electronica. Universidad ´ de Sevilla.


Figura 9. ALU: Diagrama de tercer nivel de las operaciones de suma y resta con signo.


Figura 10. ALU: Diagrama de tercer nivel de la operacion de multiplicaci ´ | on´
con signo.


Figura 11. ALU: Diagrama de tercer nivel del submodulo correspondiente al ´ multiplicador en binario natural.

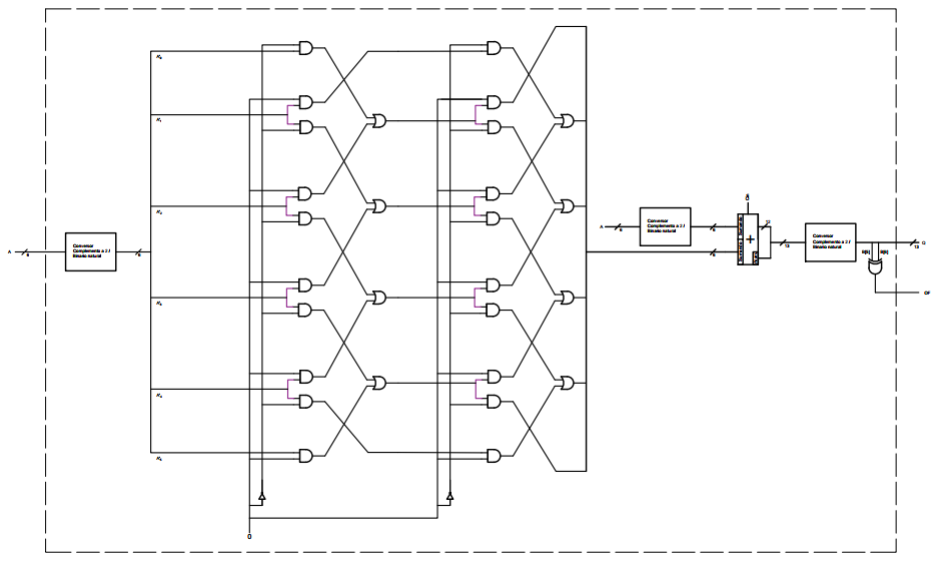
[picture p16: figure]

Figura 12. ALU: Diagrama de tercer nivel de la operacion de quintuplicado ´ de un numero. ´

DITTEL, GONZALEZ, NARANJO, NAVARRO, RODR ´ | ÍGUEZ, DISENO E IMPLEMENTACI ˜ | ON DE UNA ALU | 6 ´


Figura 13. ALU: Detalle del circuito quintuplicador de un numero. ´

Figura 14. ALU: Diagrama de tercer nivel para la bandera ZF.

Figura 15. ALU: Diagrama de tercer nivel para la bandera PF.

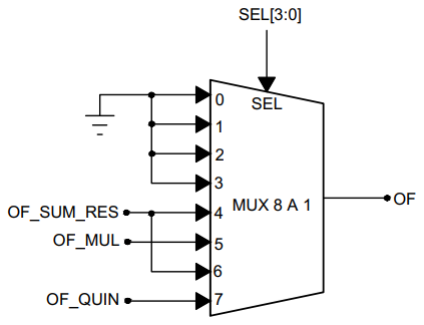
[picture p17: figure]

Figura 16. ALU: Diagrama de tercer nivel para la bandera OF.

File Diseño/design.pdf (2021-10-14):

INSTITUTO TECNOLÓGICO DE COSTA RICA

ÁREA ACADÉMICA DE INGENIERÍA MECATRÓNICA

MT 4002
Laboratorio de Electrónica Digital

Proyecto 2:
Diseño e implementación de una ALU

Jose Fabio Navarro Naranjo – 2019049626

Adrián Dittel Retana – 2019007945

Gabriel González Rodríguez – 2019057548

Emmanuel Naranjo Blanco – 2019053605

David Rodríguez Camacho – 2019024546

Profesora: Ana María Murillo Morgan

Semestre II - 2021

Contenido

I. Descripción del proyecto

En el presente proyecto se diseñará una unidad aritmética lógica que realiza todas las

operaciones mostradas en la Tabla 1. Para esto se cuenta con tres entradas y cuatro salidas,

las cuales a través de una implementación en Verilog permitirá integrar las operaciones

correspondientes.

En la Figura 1 se indica el diagrama de primer nivel del problema por resolver, donde las

entradas A y B son los operandos de 6 bits, SEL es el seleccionador de la ALU de 3 bits. En

cuanto a las salidas se tiene Y de 6 bits como resultado de la operación, y tres banderas, ZF

como bandera de cero, PF como bandera de paridad y OF como bandera de desbordamiento.

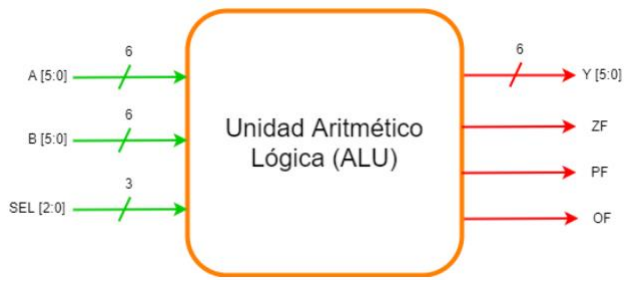
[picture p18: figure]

Figura 1. Diagrama de entradas y salidas del sistema a diseñar.

Tabla 1. Descripción de las operaciones de la ALU.

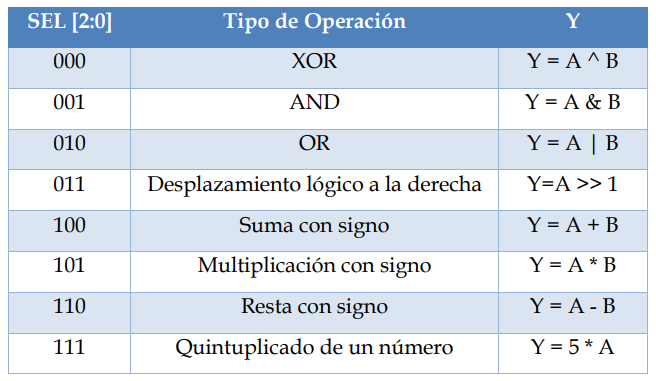
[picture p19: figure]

II. | Diseño propuesto
| Con el fin de llegar a una solución concreta, se particionó el problema en módulos, cada uno
| con su función correspondiente. En la sección de Anexos se presenta el diagrama de primer
| y segundo nivel para la solución propuesta del proyecto y en las siguientes secciones se
| explicará a fondo cada módulo planteado. En este se observa que según el SEL, la ALU
| escoge el resultado de una operación, cuyas entradas A y B, y la salida Y son de 6 bits.
| Además, se presentan los módulos de las tres banderas ZF, PF y OF, cada uno con su lógica
| combinacional correspondiente.
| Cabe destacar que en los MUX empleador, todos se encuentran habilitados, por lo que el
| Enable es 1 y se decidió omitir de los diagramas.

III. Banderas

### 1. Bandera ZF

| Para la bandera de cero, o la “Zero Flag”, el diseño se basó en colocar una compuerta del tipo
| NOR que capte todos los bits de salida del resultado de las operaciones, de modo que (al ser
| una compuerta NOR) arroje un 1 únicamente cuando todos los bits de Y sean 0.

### 2. Bandera PF

| Para la bandera de paridad, el diseño se basó en el hecho de que dicha bandera debe activarse
| cuando la cantidad de 1’s en el resultado es par. Por este motivo, se utilizó una compuerta
| XNOR, la cual recibe como entrada todos los bits del resultado Y, debido a su
| funcionamiento (arroja un 1 siempre que la cantidad de 1’s en la entrada sea par) provocará
| que la bandera de paridad se active cuando la cantidad de bits iguales a 1 en la salida sea par.

### 3. Bandera OF

| Esta bandera presenta un grado de complejidad mayor a las anteriores. Para diseñar esta
| bandera lo que se hizo fue implementar en el circuito de cada operación, una salida que
| representa si existe Over Flow en la operación realizada (dichos diseños se presentan más
| adelante en el diseño del circuito para cada operación). Entonces, se toman todas estas salidas
| y se dirigen hacia un multiplexor 8 a 1, el cual usa el mismo selector del multiplexor que saca
| el bus de datos de las operaciones, de esta manera, se conecta la bandera de Over Flow a la
| salida de este multiplexor, y se refleja el Over Flow de la operación que se está realizando.
| Es importante mencionar que para las operaciones lógicas (AND, OR, XOR,
| Desplazamiento), el Over Flow siempre es 0, por este motivo, las primeras 4 entradas del
| multiplexor se conectan a tierra. Por último, también se hace énfasis, en que se diseñó un
| solo circuito para la operación de suma y resta, y por ende, este circuito saca el Over Flow
| de la operación que se está realizando, por este motivo, las entradas 4 y 6 del multiplexor se
| encuentran en corto circuito con la salida del circuito Sumador/Restador.

El diagrama de diseño de las 3 banderas se presenta en la sección de Anexos junto con los

demás diagramas.

IV. Proceso de diseño de las operaciones

En la presente sección se muestra la partición del problema, con el fin de desarrollar

subsistemas y posteriormente integrarlo en un producto final. Cada operación se realiza según

el seleccionador de la ALU, SEL [2:0].

### 4. Operación XOR

Para esta operación, el diseño implementó el uso de 6 compuertas XOR (representadas como

una sola, que tiene como ingreso y salida un bis de datos), las cuales comparan los bits de A

contra los de B en el orden de significancia, es decir, la primera compuerta XOR compara el

bit A0 con el bit B0, la segunda compuerta compara el bit A1 con el bit B1, y así

sucesivamente hasta que se llega a la última compuerta que compara el bit más significativo

de cada entrada. Por último, el bus de salida tiene 6 bits, los cuales son tomados de cada

compuerta utilizada.

### 5. Operación AND

El diseño para el circuito que ejecuta esta operación es bastante similar al implementado en

la operación anterior, solo que con otro tipo de compuertas lógicas. Utiliza 6 compuertas del

tipo AND, las cuales comparan bit por bit, las entradas A y B, desde el bit menos

significativo, hasta el bit más significativo, de modo que este circuito arroja como salida un

bus de 6 bits, que incluye todas las salidas individuales de cada compuerta.

### 6. Operación OR

De manera bastante similar a las anteriores, esta operación se realiza con 6 compuertas OR

que comparaban uno a uno los bits de las entradas A y B, conforme a su significancia, de

modo que al circuito le entran los 6 bits de A, y los 6 bits de B, y tiene como salida un bus

de datos que se dirige al multiplexor, y que representa las salidas de cada compuerta OR

individual.

### 7. Desplazamiento lógico a la derecha

Para el diseño de este circuito lógico, no se utilizó ninguna compuerta lógica. Lo que se

realizó fue que se alambraron los bits de A, de modo que calzaran con el bit de Y esperado.

Para esto, se utilizó de manera ilustrativa la Tabla 2, con el fin de tener una idea más clara de

las conexiones a realizar.

Tabla 2. Tabla para las conexiones del circuito de desplazamiento a la derecha.

Bus de datos | Bits
A | A5 | A4 | A3 | A2 | A1 | A0
Y | 0 | A5 | A4 | A3 | A2 | A1

Con ayuda de la tabla anterior, se observó que lo que se debía realizar era tomar como 0 el

bit más significativo de la salida, y luego, únicamente alambrar las entradas de A con las

salidas, de manera que se cumpliera lo expuesto en la Tabla 2.

### 8. Suma con signo y Resta con signo

Se determinó apropiado la integración de la suma y resta con signo en un único módulo, el

cual realizará una de las dos operaciones según el bit 1 del seleccionador de la ALU, SEL[1].

Como se observa en la Tabla 1, este corresponde a 0 cuando se escoge la suma de A y B, y

equivale a 1 cuando se realiza la resta.

A partir de esto, se procedió a utilizar un sumador donde A se conecta directamente a una de

sus entradas y B procede de la salida de un multiplexor gobernado por SEL[1], en una entrada

del MUX B se mantiene igual y en la otra se invierte con compuertas NOT. Igualmente, el

acarreo de entrada corresponde a SEL[1]. De este modo, al escoger la suma, A y B se

mantienen iguales y Cin=0, pero al escoger la resta, A se mantiene y se aplica el complemento

a 2 de B gracias a que este se niega a causa de la salida del MUX y se suma un 1 con el

Cin=1. Para comprender mejor esto, se invita a observar la sección de Anexos, donde se

muestra el diagrama de tercer nivel para la operación conjunta de suma y resta en

complemento a 2.

En cuanto al desbordamiento, por un lado, en la suma esta condición puede ocurrir solo

cuando los operandos son del mismo signo y siempre produce un resultado incorrecto. Por

otro lado, en la resta el desbordamiento sucede cuando los números tienen signos diferentes

(Tocci, 2007). Además, al trabajar bajo el sistema de complemento a 2, se sabe que tanto

para resta como suma, si el número es negativo, se realizará el complemento a 2 de este y se

hará la operación de suma. Por esta razón, el desbordamiento ocurre únicamente cuando el bit más significativo de los operandos es igual y el bit más significativo del resultado es

distinto al MSB de los operandos.

Para obtener el desbordamiento se hizo la tabla de verdad (Tabla 3) y mediante la suma de

productos se obtuvo la ecuación correspondiente, la cual fue implementada en compuertas

lógicas.

Tabla 3. Tabla de verdad para detectar el desbordamiento de la suma y resta con signo.

| | Entradas | | Salidas
# | A [5] | B [5] | Y [5] | OF

0 | 0 | 0 | 0 | 0
1 | 0 | 0 | 1 | 1
2 | 0 | 1 | 0 | 0
3 | 0 | 1 | 1 | 0
4 | 1 | 0 | 0 | 0
5 | 1 | 0 | 1 | 0
6 | 1 | 1 | 0 | 1
7 | 1 | 1 | 1 | 0

La función de desbordamiento corresponde a:

OF = A[5]

̅̅̅̅̅̅ ∙ B[5]

̅̅̅̅̅̅ ∙ Y[5] + A[5] ∙ B[5] ∙ Y[5] ̅̅̅̅̅̅

### 9. Multiplicación con signo

Para el diseño del multiplicador se utilizó el mismo proceso que se utilizaría para resolver

una operación binaria en complemento a dos a mano. Este proceso consiste de tres pasos.

Primero, se hace la conversión de complemento a 2 a binario natural para los operandos que

tengan signo negativo. Segundo, se realiza la multiplicación binaria habitual con ambos

operandos en binario natural. Tercero, se hace una comprobación, por “ley de signos”, para

determinarsi el resultado debe de tener signo negativo o positivo. Esto significa que,si ambos

operandos tienen el mismo signo, el resultado va a ser positivo, y si tienen signos opuestos,

el resultado va a ser negativo.

Entrando un poco más a fondo en el diseño del primer paso, explicado en el párrafo anterior,

se utiliza un multiplexor (Mux) 2 a 1 para elegir entre dos opciones, o se deja pasar el

operando a como entró al módulo originalmente, o se deja pasar este, pero habiéndole hecho la conversión en complemento a 2. Como selector del Mux se utiliza el bit más significativo

del dato de entrada, ya que este corresponde al signo, si es 0 (positivo) se deja pasar el

operando tal y como venía, si es 1 (negativo) se realiza la conversión. La conversión en

complemento a 2, ya propiamente, consiste en un inversor, para cada bit del operando, y de

un sumador entre el operando y el número 1 (procedimiento para la conversión en

complemento a 2). A la salida del mux entonces saldría únicamente el dato en su

representación en binario natural. La anterior explicación se puede visualizar en la página 5

de los anexos, que corresponde al Diagrama de Tercer Nivel: Multiplicador con Signo.

Una vez teniendo ambos operandos en su representación en binario natural, se procede con

el multiplicador, el cual está formado a partir de sumadores, a como se observa en la página

6 de los anexos que corresponde al Diagrama de Tercer Nivel: Detalle Multiplicador. En este

se anidan los sumadores en la configuración mostrada, y con las compuertas AND; para

realizar la multiplicación entre ambos operandos. Para el caso de este diseño, como se está

trabajando con un tamaño de palabra de 6 bits, únicamente se dejan como salida los bits del

0 al 5, y al bit 5 se le asigna un 0 lógico ya que este correspondería al signo en complemento

a dos. De esta forma se obtienen solo los datos de los bits se necesitan representar. Para

detectar si existe desbordamiento, u “overlflow”, se toman como entrada para una compuerta

OR los bits no utilizados anterior mente (bits del 6 al 11) y de esta forma si alguno posee un

1 lógico (lo que significa que hubo desbordamiento) la salida de la compuerta (la bandera de

desbordamiento, o bandera OF) tendría un 1 lógico a la salida, en caso contrario tendría un 0

lógico.

Por último, para el caso del convertir el resultado de la multiplicación, que se encuentra en

binario natural, a complemento a 2, se utiliza el mismo conversor, descrito anteriormente,

para la conversión del operando negativo en complemento a 2 a binario natural, ya que el

procedimiento es el mismo sin importar la dirección de la conversión. La única diferencia

con esta configuración anterior es que al selector le entra el resultado de una compuerta XOR

que tiene como entradas el bit más significativo de cada operando. De esta forma, si los

signos de los operandos son diferentes (que corresponde a un resultado negativo), se realiza

la conversión, en caso contrario se deja pasar el resultado a como se obtuvo de la

multiplicación en binario natural.

### 10. Quintuplicado de un número

En cuanto a la operación del quintuplicador, se hizo la multiplicación por 5 a partir del

principio de desplazamiento a la izquierda. Dado que esto solo sirve para multiplicar por números resultantes de 2n

se separó el cinco en una suma de potencias de 2, 2²+2⁰ , entonces

se corre el número entrante dos veces a la izquierda y se suma a la entrada original para

obtener la función x ∗ (2

2 + 2

0
). Para esto se hizo el desplazador mostrado en la Figura 2

para correr el complemento a dos del número.


Figura 2. Circuito desplazador del quintuplicador.

En este circuito, cuando se le ingresa un 0 en las entradas de las AND rojas, esto va a hacer

que las AND rojas corten el paso a su dígito de entrada y las azules, gracias a la NOR van a

tener un 1 y van a dejar pasar su entrada (si entra un 1 va a salir un 1 y si entra un 0 va a pasar

un 0). Así, como las salidas están organizadas se va a correr el dígito de entrada hacia la

izquierda una vez. Para conseguir que se corriera dos veces, las salidas de este circuito se

conectan a otro desplazador igual y luego este resultado se ingresa a un sumador de 6 bits

junto al número original para obtener la multiplicación por cinco.

Para calcular el desbordamiento se tomó en cuenta que “overflow occurs if and only if

pn⊕pn-1 = 1” (Gok et al., 2006, p.1065); es decir, si el XOR de los bits n y n-1 del producto

(en este caso 6 y 5 porque n es la cantidad de bits de las entradas) va a haber desbordamiento.

Entonces para cumplir esto en la salida del quintuplicador se conectaron los bits 6 y 5 a una

compuerta XOR y si esta devuelve un 1 el desbordamiento ocurre. Para observar el diseño completo es indispensable visitar la sección de Anexos, donde está el diagrama de tercer

nivel de esta función quintuplicador.

Referencias

Gok, M. Schulte, M. Arnold, M. (2006). Integer Multiplier with Overflow Detection. https://www.researchgate.net/publication/3045091_Integer_multipliers_with_overflow_detection (https://www.researchgate.net/publication/3045091_Integer_multipliers_with_overflow_detection)

Tocci, R. (2007). Sistemas digitales: Principios y aplicaciones. Décima Edición. Pearson Education.

V. Anexos

En la presente sección se adjuntan los diagramas de primer, segundo y tercer nivel propuestos

para la integración del diseño final del proyecto. Estos diagramas se dividen en páginas, cada

una indicando los diseños particulares explicados anteriormente.

Índice de los diagramas para implementar la ALU:

Página 1. Diagrama de primer nivel.

Página 2. Diagrama de segundo nivel.

Página 3. Diagrama de tercer nivel: XOR, AND, OR y desplazamiento a la derecha.

Página 4. Diagrama de tercer nivel: Banderas de Zero, Paridad, y de Desbordamiento.

Página 5. Diagrama de tercer nivel: multiplicador con signo.

Página 6. Diagrama de tercer nivel: detalle multiplicador.

Página 7. Diagrama de tercer nivel circuito sumador y restador.

Página 8. Diagrama de tercer nivel del circuito quintuplicador.

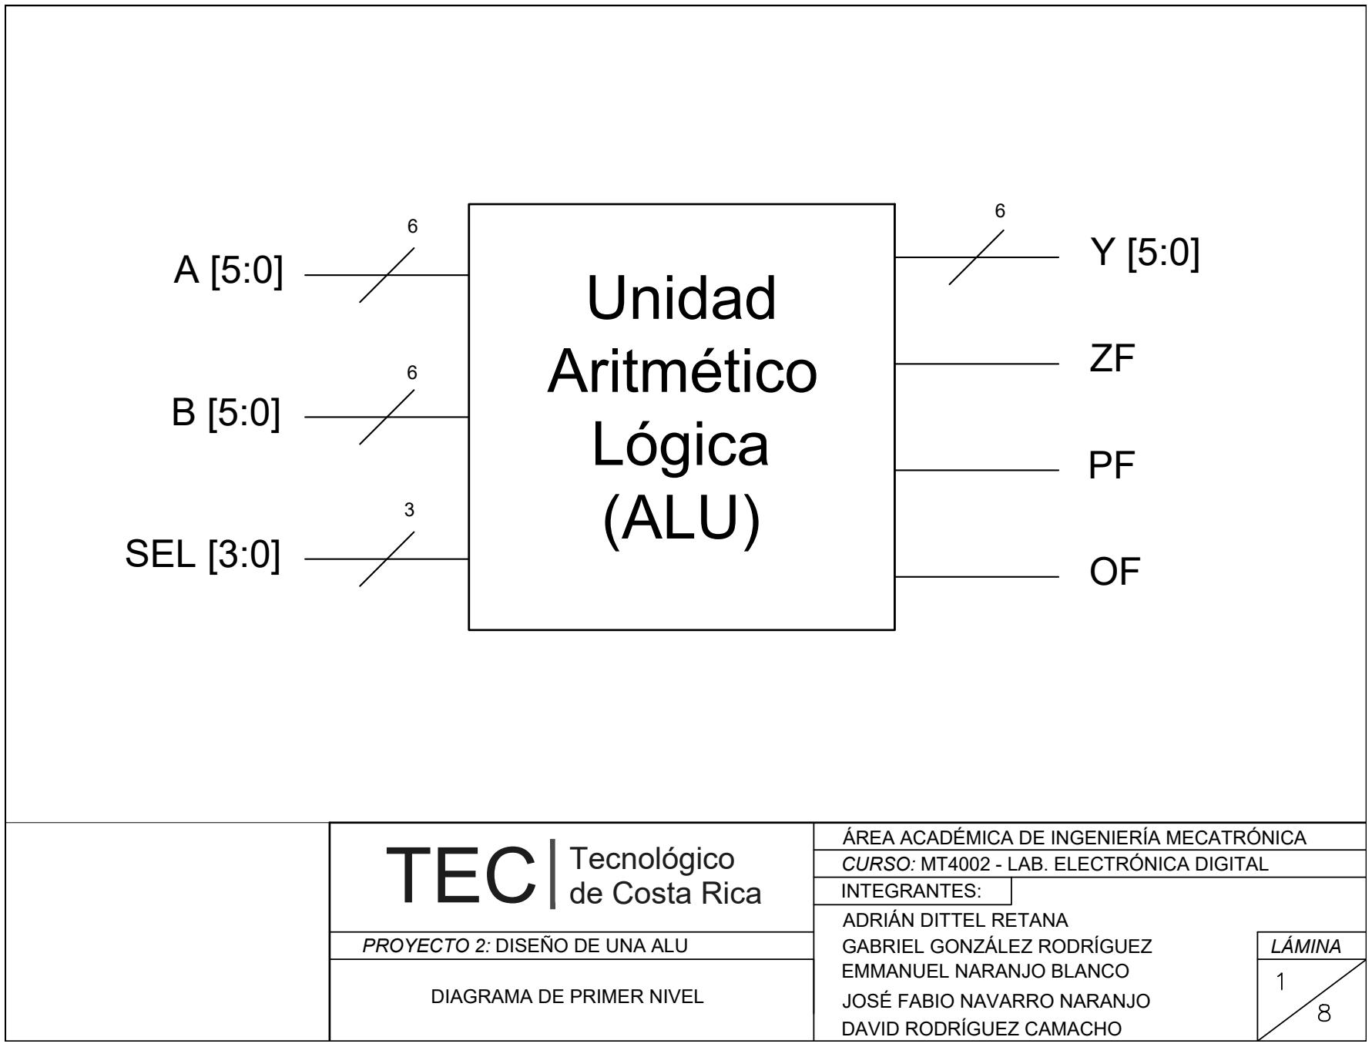
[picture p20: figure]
Unidad Aritmético Lógica; (ALU); SEL [3:0]; OF PFZFY [5:0]

6 PROYECTO 2: DISEÑO DE UNA ALU | CURSO: MT4002 - LAB. ELECTRÓNICA DIGITALLÁMINA TEC Tecnológico de Costa Rica | ÁREA ACADÉMICA DE INGENIERÍA MECATRÓNICA DIAGRAMA DE PRIMER NIVEL | INTEGRANTES: GABRIEL GONZÁLEZ RODRÍGUEZ ADRIÁN DITTEL RETANA JOSÉ FABIO NAVARRO NARANJO

### DAVID RODRÍGUEZ CAMACHO EMMANUEL NARANJO BLANCO

## CREADO CON UNA VERSIÓN PARA ESTUDIANTES DE AUTODESK

## CREADO CON UNA VERSIÓN PARA ESTUDIANTES DE AUTODESK

## CREADO CON UNA VERSIÓN PARA ESTUDIANTES DE AUTODESK

## CREADO CON UNA VERSIÓN PARA ESTUDIANTES DE AUTODESK

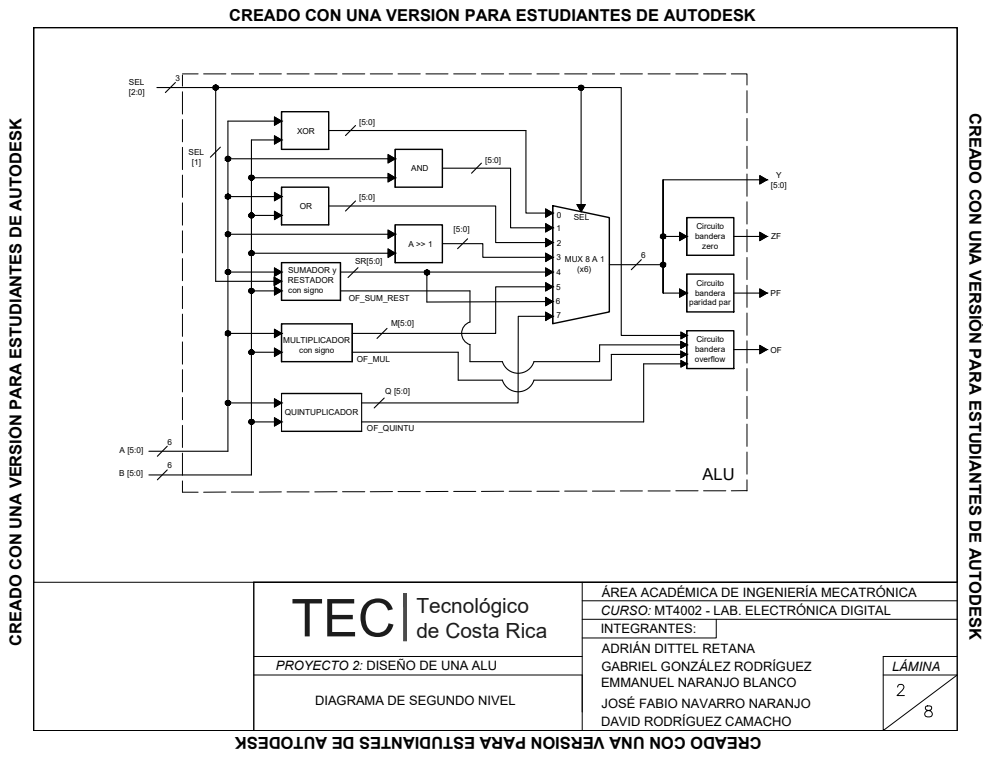
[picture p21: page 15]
XOR; AND OR; A >> 1 SUMADOR y RESTADOR con signo MULTIPLICADOR con signo QUINTUPLICADOR; MUX 8 A 1 (x6) Q [5:0] M[5:0]; Circuito bandera zero Circuito bandera paridad par Circuito bandera overflow; Y[5:0] ZFPFOF OF_QUINTU OF_MUL OF_SUM_REST; ALU SEL [1] SEL [2:0] A [5:0] B [5:0]; 7 SEL; 6 PROYECTO 2: DISEÑO DE UNA ALU; CURSO: MT4002 - LAB. ELECTRÓNICA DIGITALLÁMINA TEC Tecnológico de Costa Rica; ÁREA ACADÉMICA DE INGENIERÍA MECATRÓNICA DIAGRAMA DE SEGUNDO NIVEL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

CREADO CON UNA VERSIÓN PARA ESTUDIANTES DE AUTODESK

DAVID RODRÍGUEZ CAMACHO EMMANUEL NARANJO BLANCO

## CREADO CON UNA VERSIÓN PARA ESTUDIANTES DE AUTODESK

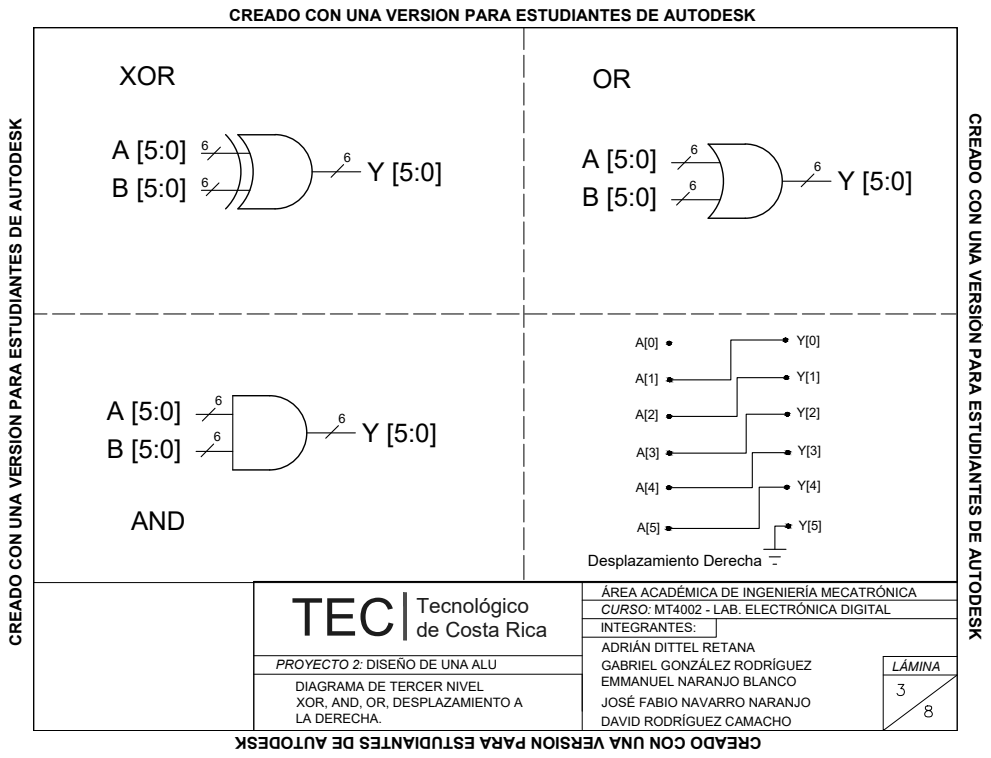
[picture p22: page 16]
PROYECTO 2: DISEÑO DE UNA ALU; LÁMINA CURSO: MT4002 - LAB. ELECTRÓNICA DIGITAL TEC Tecnológico de Costa Rica; ÁREA ACADÉMICA DE INGENIERÍA MECATRÓNICA DIAGRAMA DE TERCER NIVEL XOR, AND, OR, DESPLAZAMIENTO A LA DERECHA.; INTEGRANTES: GABRIEL GONZÁLEZ RODRÍGUEZ ADRIÁN DITTEL RETANA JOSÉ FABIO NAVARRO NARANJO DAVID RODRÍGUEZ CAMACHO EMMANUEL NARANJO BLANCO XOR; OR AND; Desplazamiento Derecha A [5:0] B [5:0]

CREADO CON UNA VERSIÓN PARA ESTUDIANTES DE AUTODESK

## CREADO CON UNA VERSIÓN PARA ESTUDIANTES DE AUTODESK

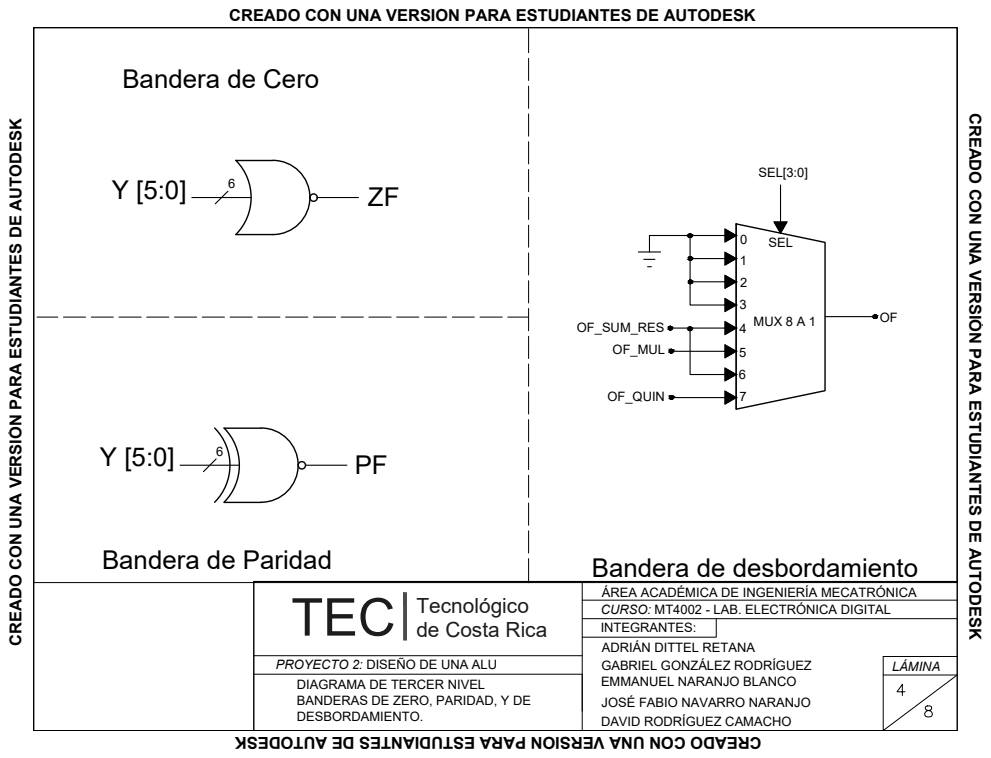
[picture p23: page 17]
PROYECTO 2: DISEÑO DE UNA ALU; LÁMINA CURSO: MT4002 - LAB. ELECTRÓNICA DIGITAL TEC Tecnológico de Costa Rica; ÁREA ACADÉMICA DE INGENIERÍA MECATRÓNICA DIAGRAMA DE TERCER NIVEL BANDERAS DE ZERO, PARIDAD, Y DE DESBORDAMIENTO.; INTEGRANTES: GABRIEL GONZÁLEZ RODRÍGUEZ ADRIÁN DITTEL RETANA JOSÉ FABIO NAVARRO NARANJO DAVID RODRÍGUEZ CAMACHO EMMANUEL NARANJO BLANCO Bandera de Cero Bandera de Paridad; Bandera de desbordamiento MUX 8 A 1 SEL[3:0] OF_SUM_RES OF_QUIN OF_MUL; SEL

CREADO CON UNA VERSIÓN PARA ESTUDIANTES DE AUTODESK

## CREADO CON UNA VERSIÓN PARA ESTUDIANTES DE AUTODESK

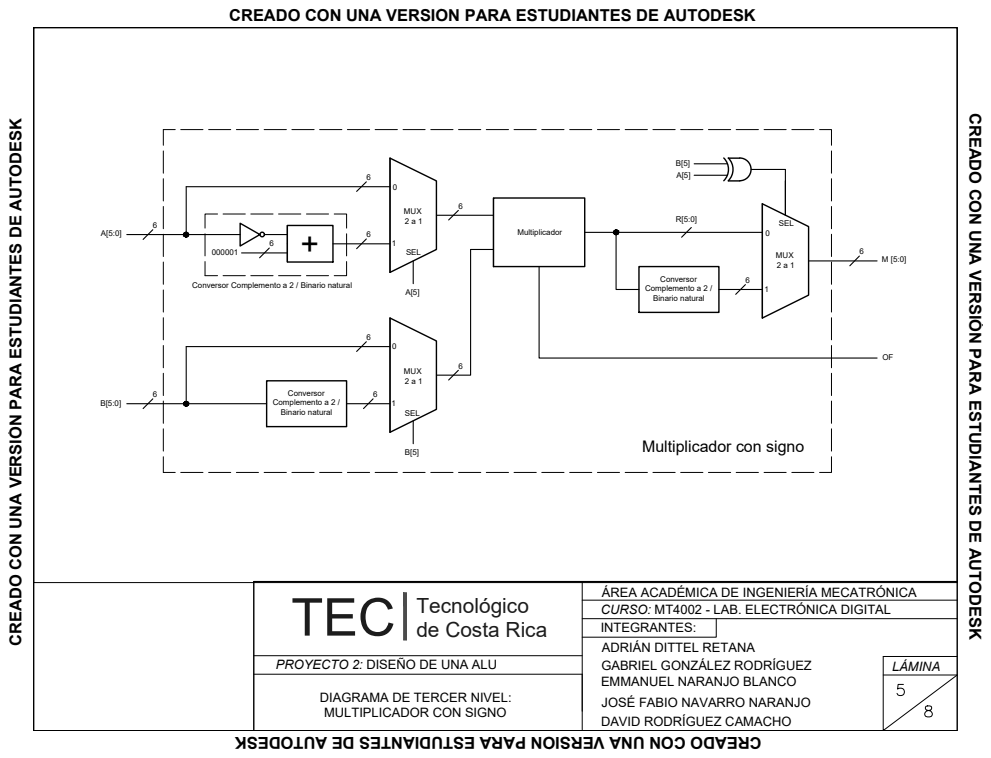
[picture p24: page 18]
MUX 2 a 1 A[5]; B[5] Conversor Complemento a 2 / Binario natural; MUX 2 a 1 Multiplicador; M [5:0] SEL; OF MUX 2 a 1 B[5]; Conversor Complemento a 2 / Binario natural R[5:0]; 1 SEL; 6 PROYECTO 2: DISEÑO DE UNA ALU; LÁMINA CURSO: MT4002 - LAB. ELECTRÓNICA DIGITAL TEC Tecnológico de Costa Rica; ÁREA ACADÉMICA DE INGENIERÍA MECATRÓNICA DIAGRAMA DE TERCER NIVEL: MULTIPLICADOR CON SIGNO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

CREADO CON UNA VERSIÓN PARA ESTUDIANTES DE AUTODESK

+ Conversor Complemento a 2 / Binario natural

Multiplicador con signo

## CREADO CON UNA VERSIÓN PARA ESTUDIANTES DE AUTODESK

Multiplicador; PROYECTO 2: DISEÑO DE UNA ALU; LÁMINA CURSO: MT4002 - LAB. ELECTRÓNICA DIGITAL TEC Tecnológico de Costa Rica; ÁREA ACADÉMICA DE INGENIERÍA MECATRÓNICA DIAGRAMA DE TERCER NIVEL: DETALLE MULTIPLICADOR; INTEGRANTES: GABRIEL GONZÁLEZ RODRÍGUEZ ADRIÁN DITTEL RETANA JOSÉ FABIO NAVARRO NARANJO DAVID RODRÍGUEZ CAMACHO EMMANUEL NARANJO BLANCO

CREADO CON UNA VERSIÓN PARA ESTUDIANTES DE AUTODESK

Sumando Sumando Acarr. A[5:1] B0A0

Sumando Sumando Acarr. B4 [1] B1 OF R5 R4 R3 R2 R1

Sumando Sumando Acarr.

Sumando Sumando Acarr. B3

## CREADO CON UNA VERSIÓN PARA ESTUDIANTES DE AUTODESK

MUX 2 a 1 B[5:0]; S[5:0] Cin; Cout SUMADOR SEL[1]; SR [5:0] Cout A[5:0] B[5:0] Y[5:0] A[5:0] B[5:0] Y[5:0]; OF_SUM_REST Detalle del circuito Circuito Sumador y Restador; 1 SEL; 6 PROYECTO 2: DISEÑO DE UNA ALU; LÁMINA CURSO: MT4002 - LAB. ELECTRÓNICA DIGITAL TEC Tecnológico de Costa Rica; ÁREA ACADÉMICA DE INGENIERÍA MECATRÓNICA DIAGRAMA DE TERCER NIVEL CIRCUITO SUMADOR Y RESTADOR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

CREADO CON UNA VERSIÓN PARA ESTUDIANTES DE AUTODESK

6 | 6 A | A'0 A'1 A'2 A'3 A'4 A'5

## CREADO CON UNA VERSIÓN PARA ESTUDIANTES DE AUTODESK

QOF 12; B[6] PROYECTO 2: DISEÑO DE UNA ALU; LÁMINA CURSO: MT4002 - LAB. ELECTRÓNICA DIGITAL TEC Tecnológico de Costa Rica; ÁREA ACADÉMICA DE INGENIERÍA MECATRÓNICA DIAGRAMA DE TERCER NIVEL DEL CIRCUITO QUINTUPLICADOR; INTEGRANTES: GABRIEL GONZÁLEZ RODRÍGUEZ ADRIÁN DITTEL RETANA JOSÉ FABIO NAVARRO NARANJO DAVID RODRÍGUEZ CAMACHO EMMANUEL NARANJO BLANCO

CREADO CON UNA VERSIÓN PARA ESTUDIANTES DE AUTODESK

Sumando Sumando Acarr. Cin Conversor Complemento a 2 / Binario natural 6 6 A Conversor Complemento a 2 / Binario natural 13 13

Conversor Complemento a 2 / Binario natural

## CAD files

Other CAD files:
Diseño/Diagramas_ALU_v6.dwg

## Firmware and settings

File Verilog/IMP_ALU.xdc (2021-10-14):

## This file is a general .xdc for the Basys3 rev B board
## To use it in a project:
## - uncomment the lines corresponding to used pins
## - rename the used ports (in each line, after get_ports) according to the top level signal names in the project

# Clock signal
set_property PACKAGE_PIN W5 [get_ports CLK100MHZ]							
	set_property IOSTANDARD LVCMOS33 [get_ports CLK100MHZ]
	create_clock -add -name sys_clk_pin -period 10.00 -waveform {0 5} [get_ports CLK100MHZ]
 
# Switches
set_property PACKAGE_PIN V17 [get_ports {SEL[0]}]					
	set_property IOSTANDARD LVCMOS33 [get_ports {SEL[0]}]
set_property PACKAGE_PIN V16 [get_ports {SEL[1]}]					
	set_property IOSTANDARD LVCMOS33 [get_ports {SEL[1]}]
set_property PACKAGE_PIN W16 [get_ports {SEL[2]}]					
	set_property IOSTANDARD LVCMOS33 [get_ports {SEL[2]}]
set_property PACKAGE_PIN W17 [get_ports {A[0]}]					
	set_property IOSTANDARD LVCMOS33 [get_ports {A[0]}]
set_property PACKAGE_PIN W15 [get_ports {A[1]}]					
	set_property IOSTANDARD LVCMOS33 [get_ports {A[1]}]
set_property PACKAGE_PIN V15 [get_ports {A[2]}]					
	set_property IOSTANDARD LVCMOS33 [get_ports {A[2]}]
set_property PACKAGE_PIN W14 [get_ports {A[3]}]					
	set_property IOSTANDARD LVCMOS33 [get_ports {A[3]}]
set_property PACKAGE_PIN W13 [get_ports {A[4]}]					
	set_property IOSTANDARD LVCMOS33 [get_ports {A[4]}]
set_property PACKAGE_PIN V2 [get_ports {A[5]}]					
	set_property IOSTANDARD LVCMOS33 [get_ports {A[5]}]
set_property PACKAGE_PIN T3 [get_ports {B[0]}]					
	set_property IOSTANDARD LVCMOS33 [get_ports {B[0]}]
set_property PACKAGE_PIN T2 [get_ports {B[1]}]					
	set_property IOSTANDARD LVCMOS33 [get_ports {B[1]}]
set_property PACKAGE_PIN R3 [get_ports {B[2]}]					
	set_property IOSTANDARD LVCMOS33 [get_ports {B[2]}]
set_property PACKAGE_PIN W2 [get_ports {B[3]}]					
	set_property IOSTANDARD LVCMOS33 [get_ports {B[3]}]
set_property PACKAGE_PIN U1 [get_ports {B[4]}]					
	set_property IOSTANDARD LVCMOS33 [get_ports {B[4]}]
set_property PACKAGE_PIN T1 [get_ports {B[5]}]					
	set_property IOSTANDARD LVCMOS33 [get_ports {B[5]}]
#set_property PACKAGE_PIN R2 [get_ports {B[0]}]					
	#set_property IOSTANDARD LVCMOS33 [get_ports {B[0]}]
 

# LEDs
set_property PACKAGE_PIN U16 [get_ports {Y[0]}]					
	set_property IOSTANDARD LVCMOS33 [get_ports {Y[0]}]
set_property PACKAGE_PIN E19 [get_ports {Y[1]}]					
	set_property IOSTANDARD LVCMOS33 [get_ports {Y[1]}]
set_property PACKAGE_PIN U19 [get_ports {Y[2]}]					
	set_property IOSTANDARD LVCMOS33 [get_ports {Y[2]}]
set_property PACKAGE_PIN V19 [get_ports {Y[3]}]					
	set_property IOSTANDARD LVCMOS33 [get_ports {Y[3]}]
set_property PACKAGE_PIN W18 [get_ports {Y[4]}]					
	set_property IOSTANDARD LVCMOS33 [get_ports {Y[4]}]
set_property PACKAGE_PIN U15 [get_ports {Y[5]}]					
	set_property IOSTANDARD LVCMOS33 [get_ports {Y[5]}]
#set_property PACKAGE_PIN U14 [get_ports {LED[6]}]					
	#set_property IOSTANDARD LVCMOS33 [get_ports {LED[6]}]
#set_property PACKAGE_PIN V14 [get_ports {LED[7]}]					
	#set_property IOSTANDARD LVCMOS33 [get_ports {LED[7]}]
#set_property PACKAGE_PIN V13 [get_ports {LED[8]}]					
	#set_property IOSTANDARD LVCMOS33 [get_ports {LED[8]}]
#set_property PACKAGE_PIN V3 [get_ports {LED[9]}]					
	#set_property IOSTANDARD LVCMOS33 [get_ports {LED[9]}]
#set_property PACKAGE_PIN W3 [get_ports {LED[10]}]					
	#set_property IOSTANDARD LVCMOS33 [get_ports {LED[10]}]
#set_property PACKAGE_PIN U3 [get_ports {LED[11]}]					
	#set_property IOSTANDARD LVCMOS33 [get_ports {LED[11]}]
#set_property PACKAGE_PIN P3 [get_ports {LED[12]}]					
	#set_property IOSTANDARD LVCMOS33 [get_ports {LED[12]}]
set_property PACKAGE_PIN N3 [get_ports {ZF}]					
	set_property IOSTANDARD LVCMOS33 [get_ports {ZF}]
set_property PACKAGE_PIN P1 [get_ports {PF}]					
	set_property IOSTANDARD LVCMOS33 [get_ports {PF}]
set_property PACKAGE_PIN L1 [get_ports {OF}]					
	set_property IOSTANDARD LVCMOS33 [get_ports {OF}]
	
	
#7 segment display
#set_property PACKAGE_PIN W7 [get_ports {seg[0]}]					
	#set_property IOSTANDARD LVCMOS33 [get_ports {seg[0]}]
#set_property PACKAGE_PIN W6 [get_ports {seg[1]}]					
	#set_property IOSTANDARD LVCMOS33 [get_ports {seg[1]}]
#set_property PACKAGE_PIN U8 [get_ports {seg[2]}]					
	#set_property IOSTANDARD LVCMOS33 [get_ports {seg[2]}]
#set_property PACKAGE_PIN V8 [get_ports {seg[3]}]					
	#set_property IOSTANDARD LVCMOS33 [get_ports {seg[3]}]
#set_property PACKAGE_PIN U5 [get_ports {seg[4]}]					
	#set_property IOSTANDARD LVCMOS33 [get_ports {seg[4]}]
#set_property PACKAGE_PIN V5 [get_ports {seg[5]}]					
	#set_property IOSTANDARD LVCMOS33 [get_ports {seg[5]}]
#set_property PACKAGE_PIN U7 [get_ports {seg[6]}]					
	#set_property IOSTANDARD LVCMOS33 [get_ports {seg[6]}]

#set_property PACKAGE_PIN V7 [get_ports dp]							
	#set_property IOSTANDARD LVCMOS33 [get_ports dp]
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
